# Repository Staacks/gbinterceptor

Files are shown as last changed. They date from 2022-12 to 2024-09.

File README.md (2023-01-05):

# GB Interceptor
Capture or stream Game Boy gameplay footage via USB without modifying the Game Boy.

This open source and open hardware Game Boy adapter uses an rp2040 to capture the communication on the cartridge bus. This data is fed into an emulator, rendered and then offered as a USB video class device.

Details about the concept can be found at https://there.oughta.be/a/game-boy-capture-cartridge and an overview is given in the following video:

Youtube Video: GB Interceptor: A Game Boy capture cartridge (https://youtu.be/6mOJtrFnawk)

If you have pull-requests, bug reports or want to contribute new case designs, please do not hesitate to open an issue. For generic discussions, "show and tell" and if you are looking for support for something that is not a problem in the code here, I would recommend .

<a href="https://www.buymeacoffee.com/there.oughta.be" target="_blank">Buy Me A Coffee</a>

# Warnings

Please make sure to understand what this device does and what its limitations are. Most importantly, there is a little lag which will make it unsuitable for playing on a bis screen. It might be ok for slow games, but its focus is on recording and streaming.

Also check out the compatibility tables for host software (for example OBS) and particular games. In principle this is a USB video class device and does not require drivers, but not all software supports the unsusual video format of the Interceptor. Similarly, games should usually work, but sometimes there are some details that the Interceptor does not yet support properly and some rare things that cannot work based on the principle of this device.

* [Game Boy compatibility](https://github.com/Staacks/gbinterceptor/wiki/Game-Boy-compatibility)
* [Host software compatibility](https://github.com/Staacks/gbinterceptor/wiki/Host-software-compatibility)
* [Game compatibility](https://github.com/Staacks/gbinterceptor/wiki/Game-compatibility)

# Building the Interceptor

There is an [order and build video](https://youtu.be/Lg92tVkEE98) to guide you through the build process which I highly recommend, especially if you are not used to ordering PCBs. A [written guide can be found in this repository's wiki](https://github.com/Staacks/gbinterceptor/wiki/Build-guide).

# Usage

Simply plug the Interceptor into your Game Boy and the Game into the Interceptor. Connect the Interceptor to your computer before turning on the Game Boy. It should show up as a webcam in any software that supports USB Video devices (for example OBS Studio). Note that some software is not entirely happy with the exotic format, but it should work in most cases (see [Host software compatibility](https://github.com/Staacks/gbinterceptor/wiki/Host-software-compatibility)).

Then just turn on the Game Boy and play.

Note that you do not need to open the video stream first. The only important step is that the Interceptor is powered via USB before the Game Boy is turned on.

## Buttons

The [Mode] button (next to the LEDs) allows to switch between grayscale/green colors and toggle frame blending. Each press switches colors and frame blending is toggled each time it returns to grayscale.

The [Flash] button (near the center, usually inside the case) is only used to flash a new firmware version. Simply hold it while plugging in the USB cable. The Interceptor should appear as a storage device (like a USB stick) and you can simply drag the new firmware file (a uf2 file) into it.

## LEDs

The red LED indicates that the Interceptor is powered.

The blue LED stays on as long as the Interceptor is in sync with the game. (It may shortly turn off for a fraction of a second when the Game Boy turns the display off, i.e. when loading a level.)

# Support

While I do not give any guarantees I (and probably others too) am happy to help if I have the time.

If you are having difficulties to order, build or use your Interceptor, please do not contact me directly but use [r/thereoughtabe on reddit](https://www.reddit.com/r/thereoughtabe/) as this allows others to help and the answer might help others, too.

If you found a bug and in particular if you find glitches in a game, please check the [compatibility lists](https://github.com/Staacks/gbinterceptor/wiki) in the Wiki first to see if it is a known problem and open an issue here on Github otherwise.

# Building the firmware

Most users should just install the latest release uf2 as described in the [Build guide](https://github.com/Staacks/gbinterceptor/wiki/Build-guide), but if you want to build it yourself, you will need the [Raspberry Pi Pico SDK](https://github.com/raspberrypi/pico-sdk). Don't forget to set PICO_SDK_PATH accordingly.

Make sure to check out the submodules too and specifically make sure that the [TinyUSB](https://github.com/hathach/tinyusb) submodule is at least on version 0.14.0 as the Pico SDK currently references an older version. (Also see [#3](https://github.com/Staacks/gbinterceptor/issues/3))

# License
The code is released under the GNU General Public Licence 3 and the design files (PCB layout and 3d printed case) are released under the Creative Commons licence CC-BY 4.0.

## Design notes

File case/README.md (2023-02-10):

# GB Interceptor Case

These are various resources and design files for cases for the GB Interceptor. The 3d-printed one referenced in the Youtube videos and the build guide [build guide](https://github.com/Staacks/gbinterceptor/wiki/Build-guide) can be found in the folder 3dprint. 

**You can find more options by the community by looking at the [case guides](https://github.com/Staacks/gbinterceptor/wiki#case-options) on the Wiki.**

# Important note about the break-out extension board

If you want to create a custom case using the extension board to place the cartridge slot in a more flexible manner, please take special care to correctly match the pins. For this, ignore the silklayer (printing) ob the PCB and look at the position of pin one, which is the one with the square pad (the others are circular). The printed outline on the PCB may work fine for jumper wires or special connectors, but with the normal ribbon cable connectors (known from old disk drives) the pin headers of either the extension board or the GB Interceptor need to be soldered onto the opposite side of the board in order for the pins to match. Therefore, keep track of pin one when creating your own solution.

# Folder list

Please, find details about each option in the [case guides](https://github.com/Staacks/gbinterceptor/wiki#case-options) on the Wiki.

* __3dprint__  
  The original 3d printed case as discussed in the videos.
* __3dprint-angryhelder__  
  Variant by AngryHelder (Helder Silva) of the original 3d printed case. These are step files derived from the original 3dprint case to allow for easy adaption into new case projects. It also includes a version that is easier and nicer to print but requires glueing.

# License

The design files are licensed under the Creative Commons Attribution License (CC-BY 4.0).

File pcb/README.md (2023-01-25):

# GB Interceptor PCB

These are the design files for the PCB of the GB Interceptor. See the [build guide](https://github.com/Staacks/gbinterceptor/wiki/Build-guide) for details.

# License

The design files are licensed under the Creative Commons Attribution License (CC-BY 4.0).

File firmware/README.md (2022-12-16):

# GB Interceptor Firmware

This folder contains the source code for the firmware of the GB Interceptor. It requires the Raspberry Pi Pico SDK as well as TinyUSB (which is usually a submodule of the Pico SDK repository). If you want to build the firmware yourself, remember to set `PICO_SDK_PATH` correctly.

The subfolder screens contains the info screens shown when no game is running. The `sh` script in the same folder can be used to convert new images to header files.

# License

This code is licensed under GNU General Public License v3.

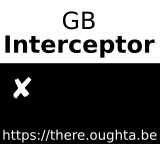
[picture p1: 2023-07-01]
firmware/screens/off.png

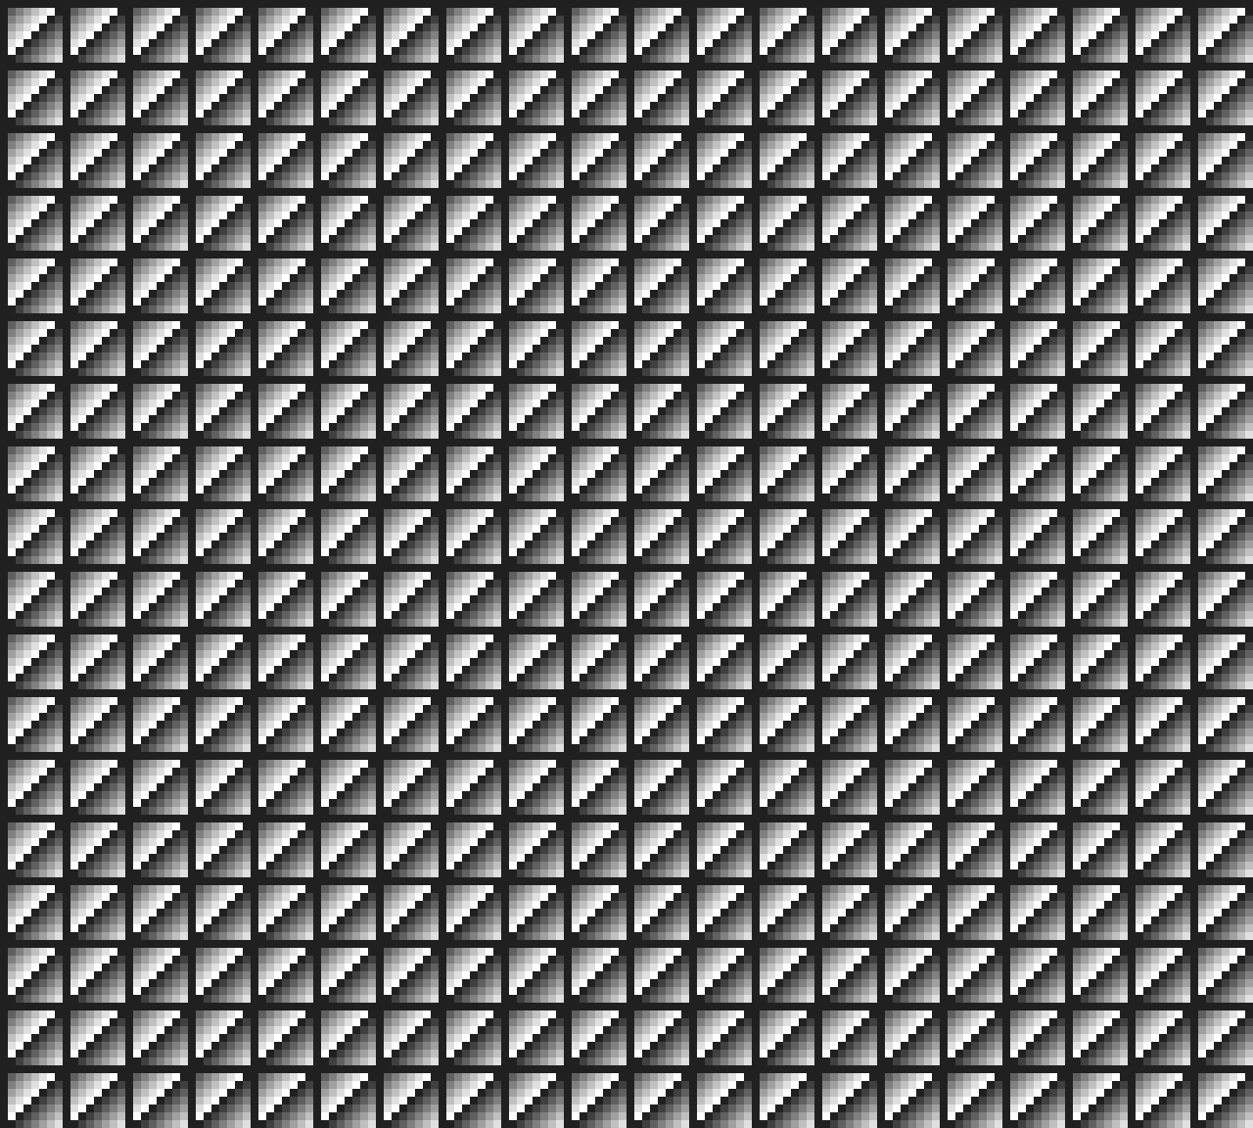
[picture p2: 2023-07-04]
firmware/jpeg/base.jpg

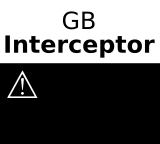
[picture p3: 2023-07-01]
firmware/screens/error.png

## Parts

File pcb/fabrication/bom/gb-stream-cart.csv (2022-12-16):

Comment | Designator | Footprint | LCSC
10u | C1,C4,C17 | Capacitor_SMD:C_0805_2012Metric | C440198
30p | C2,C3 | Capacitor_SMD:C_0402_1005Metric | C1570
100n | C5,C6,C7,C9,C11,C12,C13,C14,C15,C16,C18,C19,C20,C21,C22,C23,C24,C25 | Capacitor_SMD:C_0402_1005Metric | C1525
1u | C8,C10 | Capacitor_SMD:C_0402_1005Metric | C52923
LED BLUE | D1 | LED_SMD:LED_1206_3216Metric | C130717
LED RED | D2 | LED_SMD:LED_1206_3216Metric | C84270
USB_C_Receptacle_USB2.0 | J1 | Connector_USB:USB_C_Receptacle_HRO_TYPE-C-31-M-12 | C165948
1k | R1,R5 | Resistor_SMD:R_0402_1005Metric | C11702
5.1k | R10,R11 | Resistor_SMD:R_0402_1005Metric | C25905
27 | R3,R4 | Resistor_SMD:R_0402_1005Metric | C25100
470 | R6 | Resistor_SMD:R_0402_1005Metric | C25117
2.2k | R7,R8 | Resistor_SMD:R_0402_1005Metric | C25879
3.3k | R9 | Resistor_SMD:R_0402_1005Metric | C25890
SW_Flash | SW1 | Button_Switch_SMD:SW_Push_1P1T-SH_NO_CK_KMR2xxG | C72443
SW_Mode | SW2 | Button_Switch_SMD:SW_Push_1P1T-SH_NO_CK_KMR2xxG | C72443
NCP1117-3.3_SOT223 | U1 | Package_TO_SOT_SMD:SOT-223-3_TabPin2 | C146799
W25Q128JVS | U2 | Package_SO:SOIC-8_5.23x5.23mm_P1.27mm | C97521
RP2040 | U3 | RP2040_minimal:RP2040-QFN-56 | C2040
SN74LVC4245A | U4,U5,U6,U7 | gb-stream-cart:SN74LVC4245APWR | C7859
TAXM12M2GLFBET2T | Y1 | RP2040_minimal:Crystal_SMD_HC49-US | C111117

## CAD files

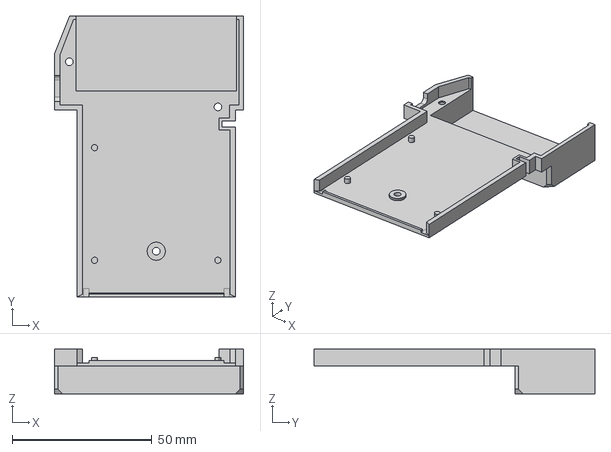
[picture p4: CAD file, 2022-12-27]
case/3dprint-angryhelder/GB Interceptor Bottom.step
67.9 x 100.7 x 16.0 mm

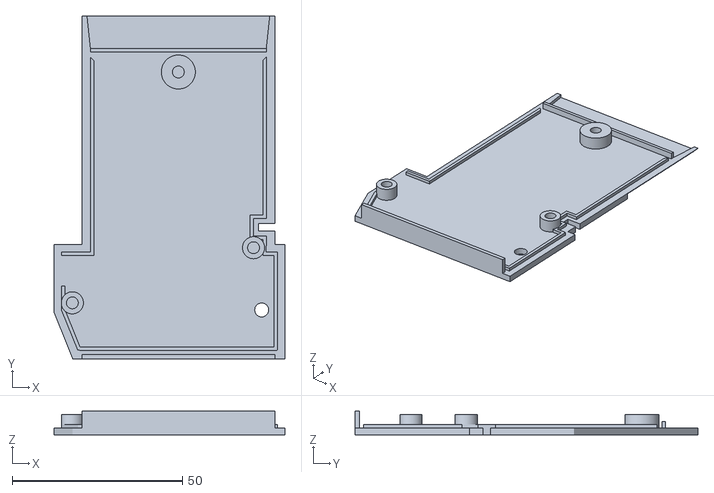
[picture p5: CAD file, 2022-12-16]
case/3dprint/case_top.stl
67.9 x 100.7 x 7.00

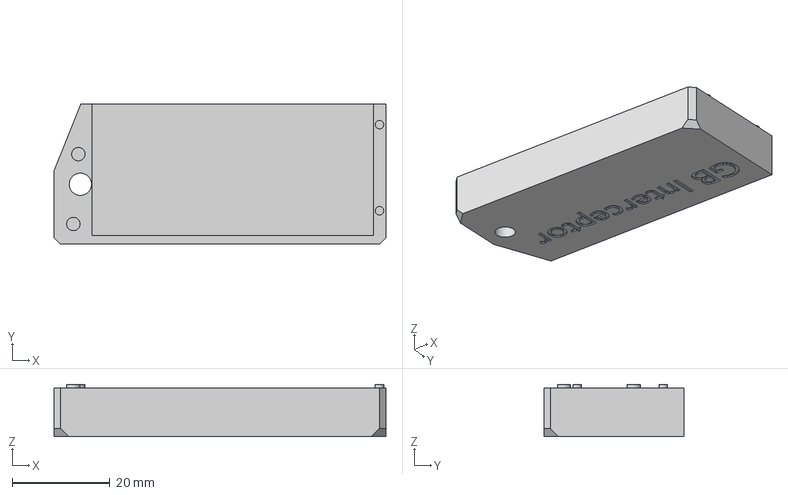
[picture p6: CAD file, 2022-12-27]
case/3dprint-angryhelder/GB Interceptor Bottom Cap.step
67.9 x 28.7 x 10.7 mm

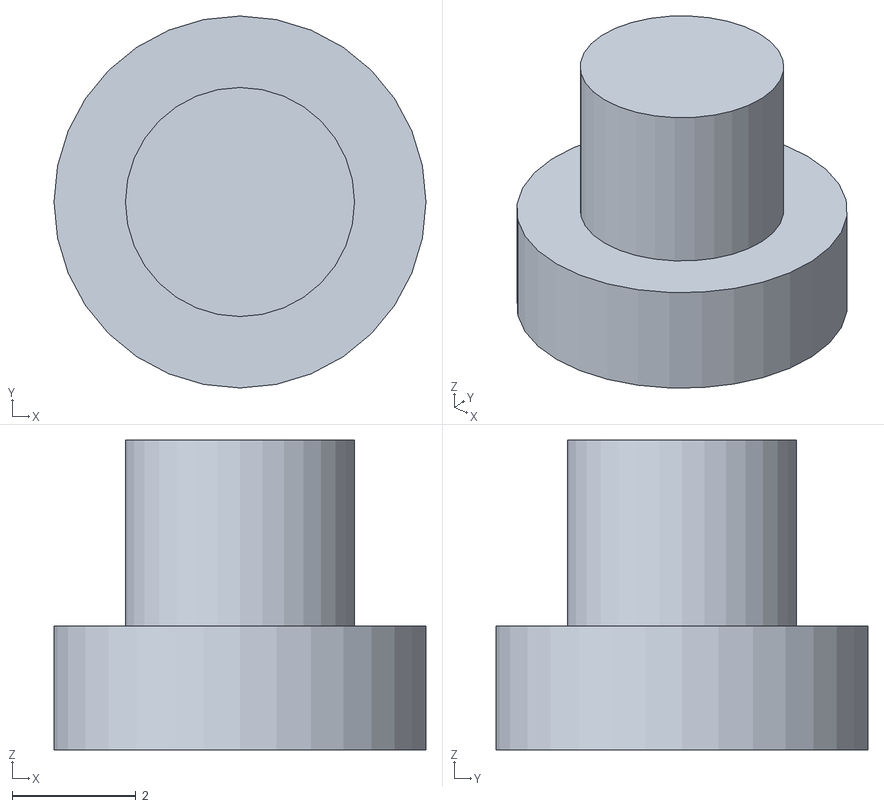
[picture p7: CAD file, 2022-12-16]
case/3dprint/case_button.stl
6.00 x 6.00 x 5.00

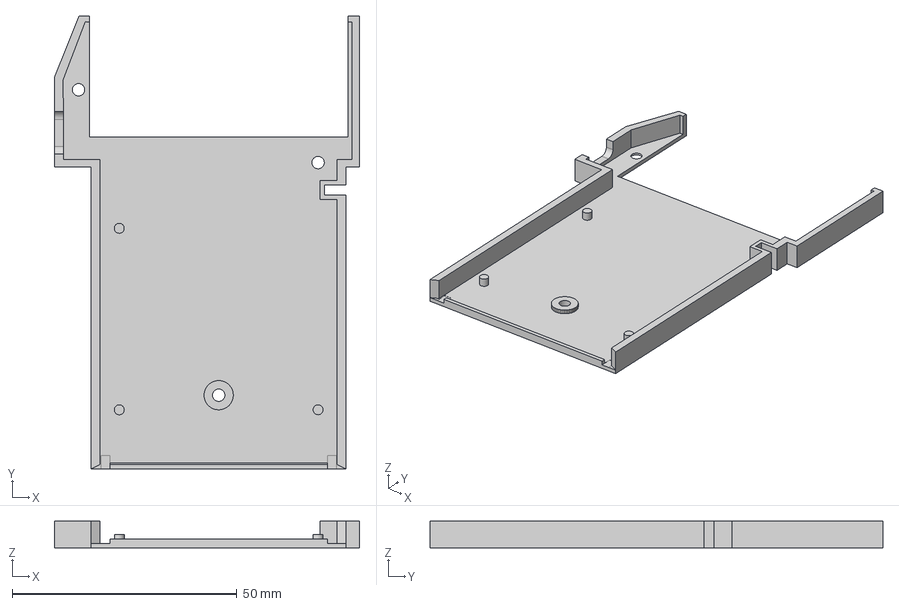
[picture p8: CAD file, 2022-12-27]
case/3dprint-angryhelder/GB Interceptor Bottom Base.step
67.9 x 100.7 x 6.00 mm

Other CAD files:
case/3dprint/case_bottom.stl
case/3dprint-angryhelder/GB Interceptor Top.step
case/3dprint-angryhelder/GB Interceptor Button.step
case/3dprint/case.blend

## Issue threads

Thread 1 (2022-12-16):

Corrupted image on MacOS on Apple CPUs

Staacks, 2022-12-16:
While the system and software recognizes the GB Interceptor, no image is received.

On first tests, the following could be found:
* Tested and not working: FaceTime, VLC, OBS, ffmpeg (on the command line)
* As not even ffmpeg and OBS get an image, I suspect that this is not an issue of the host software, but the system's USB video class driver
* The GB Interceptor does not even notice that the system requests a video stream and does not try to send a single frame.

Staacks, 2022-12-27:
**Update**:

The next release will work on MacOS to some extend. I got it to work on an Intel MacBook, but not on an M2 and I highly suspect that there is a bug in the driver for Apple silicon. The fix to at least get it to work on the Intel MacBook is in TinyUSB where I will set up a Pull Request next, so there is no commit here to reference at the moment.

Also, there is still some flickering going in case of the MacBook that works, but I have an idea what might be the cause and might be able to fix this when implementing selectable framerates...

For those Apple devices on which it will not work, we will have to wait for a fix from Apple or for a solution through a Python script without the USB video class.

Staacks, 2023-01-06:
Just some data that seems to confirm my suspicion that it is an M1/M2 thing (although a few more Intel data points would be nice)  collected from the community on Mastodon and Twitter:

Working correctly on:
MacBook Pro with **Intel** CPU that I tried
MacBook Pro (A1990) with **Intel** from #5

Green distorted image on:
MacBook Air (2022) with **M2** that I tried
MacBook Air **M1** from [@martino_](https://twitter.com/martino_/status/1610707330034987008?s=20&t=GkvNPQvVvC96-_PwVkOMTQ)
MacBook Air **M2** from [@dead_smed](https://twitter.com/dead_smed/status/1610688835981119489?s=20&t=GkvNPQvVvC96-_PwVkOMTQ)
2020 16GB **M1** Mac Mini from [@juri](https://infosec.exchange/@juri/109632195001058647)
2020 8GB **M1** MacBook Air also from [@juri](https://infosec.exchange/@juri/109632195001058647)

I am not entirely convinced that it is NV12 triggering the bug as my research at least found some reports of different NV12 devices that work on Apple silicon. But since it works on Intel-based Macs as well as Windows and Linux I still think it is either a Bug at Apple's end or at least a detail that the M1/M2 version is extremely picky about. If only I knew what triggers the issue.

LordRembo, 2023-02-01:
I tried on 2 Macbook Pro: a 2015 model and a 2017 model (first one with a touch bar).
It didn't work on Mojave (macos v10.14) -> just green image
But it started working when I upgraded the OS. I'm currently on Monterey on the oldest (v12) and Ventura on the other (v13) and the image is fine.

Staacks, 2023-02-01:
Interesting detail about Mojave. I had only tried newer versions where Intel works but M1/M2 does not. Not sure if that is related, though.

Staacks, 2023-06-17:
I just managed to get a MJPEG version of the Interceptor up and running (see #17) and it worked perfectly on an M2 MacBook Air (https://mastodon.social/@DiConX/110561770831634636).

So, I am very optimistic, that the next update will finally have full Mac compatibility.

Staacks, 2023-07-02:
Here is the first test release with MJPEG output which should fix Apple compatibility:
https://github.com/Staacks/gbinterceptor/releases/tag/v1.2.0-beta1
Please test and report back.

Staacks, 2023-08-05:
Just released version [v1.2.0](https://github.com/Staacks/gbinterceptor/releases/tag/v1.2.0) which contains the fix.

Closed 2023-08-05.

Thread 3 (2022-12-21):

Build firmware instructions

vChavezB, 2022-12-21:
**Describe the bug**
I cannot build the firmware with the latest rpi-pico sdk.

**To Reproduce**
```bash
git clone https://github.com/raspberrypi/pico-sdk --recurse-submodules
git clone https://github.com/Staacks/gbinterceptor
cd gbinterceptor/firmware
mkdir build && cd build
cmake .. -G Ninja -DPICO_SDK_PATH=../../../pico-sdk
ninja
```

**Expected behavior**

No compiler errors when building and binary output in cmake output directory.

**Error**

```bash
/gbinterceptor/firmware/main.c:265:69:` error: unknown type name 'video_probe_and_commit_control_t'
  265 | int tud_video_commit_cb(uint_fast8_t ctl_idx, uint_fast8_t stm_idx, video_probe_and_commit_control_t const *parameters) {
```

After I add this to tusb_config.h

```c
// RHPort max operational speed can defined by board.mk
// Default to Highspeed for MCU with internal HighSpeed PHY (can be port specific), otherwise FullSpeed
#ifndef BOARD_DEVICE_RHPORT_SPEED
  #if (CFG_TUSB_MCU == OPT_MCU_LPC18XX || CFG_TUSB_MCU == OPT_MCU_LPC43XX || CFG_TUSB_MCU == OPT_MCU_MIMXRT10XX || \
       CFG_TUSB_MCU == OPT_MCU_NUC505  || CFG_TUSB_MCU == OPT_MCU_CXD56 || CFG_TUSB_MCU == OPT_MCU_SAMX7X)
    #define BOARD_DEVICE_RHPORT_SPEED   OPT_MODE_HIGH_SPEED
  #else
    #define BOARD_DEVICE_RHPORT_SPEED   OPT_MODE_FULL_SPEED
  #endif
#endif

// Device mode with rhport and speed defined by board.mk
#if   BOARD_DEVICE_RHPORT_NUM == 0
  #define CFG_TUSB_RHPORT0_MODE     (OPT_MODE_DEVICE | BOARD_DEVICE_RHPORT_SPEED)
#elif BOARD_DEVICE_RHPORT_NUM == 1
  #define CFG_TUSB_RHPORT1_MODE     (OPT_MODE_DEVICE | BOARD_DEVICE_RHPORT_SPEED)
#else
  #error "Incorrect RHPort configuration"
#endif
```
It starts to compile alas I get more errors due to macros not being defined.

```bash
/gbinterceptor/firmware/usb_descriptors.h:29:86: error: 'TUD_VIDEO_DESC_CAMERA_TERM_LEN' undeclared here (not in a function); did you mean 'TUD_VIDEO_DESC_INPUT_TERM_LEN'?
```

I suspect the firmware was developed for an older version of the rpi-pico sdk, could you mention which tag or hash commit you used from the rpi-pico sdk to reproduce the build.

vChavezB, 2022-12-21:
I attempted again to build the project and now it works. Fixed by updating the tinyusb git submodule from the hash commit 4bfab30c02279a0530e1a56f4a7c539f2d35a293  to the latest release tag 0.14.0.

```
git clone https://github.com/raspberrypi/pico-sdk --recurse-submodules
cd pico-sdk/lib/tinyusb && git checkout 0.14.0 && cd ../../../
git clone https://github.com/Staacks/gbinterceptor
cd gbinterceptor/firmware
mkdir build && cd build
cmake .. -G Ninja -DPICO_SDK_PATH=../../../pico-sdk
ninja
```

Staacks, 2022-12-21:
Thanks. That should help others. I will add a note about it to the readme.

maehw, 2024-01-02:
Thanks for the additional steps. I hope it's okay when I comment on the same issue:

My build shows a warning. Can it be ignored? Or did I miss to configure something?

```
...
[76/107] Building C object CMakeFiles/gb_interceptor.dir/<some_folder>/pico-sdk/src/rp2_common/pico_stdio_usb/stdio_usb.c.obj
/<some_folder>/pico-sdk/src/rp2_common/pico_stdio_usb/stdio_usb.c:245:2: warning: #warning stdio USB was configured along with user use of TinyUSB device mode, but CDC is not enabled [-Wcpp]
  245 | #warning stdio USB was configured along with user use of TinyUSB device mode, but CDC is not enabled
      |  ^~~~~~~
[107/107] Linking CXX executable gb_interceptor.elf
```

Staacks, 2024-01-05:
Sorry, I had not noticed that warning before. It should not be a problem, though. Earlier versions of the GB Interceptor firmware had a USB serial endpoint enabled by default which I used for debugging. In recent builds I disabled it which basically means that debug message end up nowhere (but those are not triggered while the game is running anyway) unless I explicitly enable the CDC endpoint.
If the warning bothers you, you can simply set `pico_enable_stdio_usb` to `0` in https://github.com/Staacks/gbinterceptor/blob/0ad6aeca61dd41e7142bce1b27133061fd0e713e/firmware/CMakeLists.txt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
but if I am not mistaken, that should not make a difference except for the warning.

maehw, 2024-01-13:
I know this issues is closed and I wonder if I should open a new one.

The firmware builds fine. However, when I build locally, my .uf2 file does not run properly. The USB device is listed but when I open it in VLC, I don't see nothing. I've tested this on a GB Interceptor I bought online (https://chaos.social/@maehw/111744070372283492).

Overwriting my locally built one with the release version from github (https://github.com/Staacks/gbinterceptor/releases/tag/v1.2.0) makes it work again. I am quite sure this is not related to the hardware but to my local build. (I use the same git commit, i.e. 0ad6aec - the current HEAD).

Mine: filesize: 605184 bytes, md5 hash: 18781f9109015cc79da16a937391e52c
Mine (when pico_enable_stdio_usb=0): filesize: 605184 bytes, md5 hash: f76dc473397d599912e86ea8e1f09b72
Yours: 605696 bytes, md5 hash: 3207bb44884632f2e607a68629175718

How could I debug this in the best way? Binary diff the .uf2 files, the .hex files?
I use pico-sdk commit 6a7db34 (tag: 1.5.1).

Sorry if I missed something.

Staacks, 2024-01-14:
Sorry, I don't have much spare time at the moment, but hopefully I can try a build with entirely clean pulls this evening.

However, I already have a suspicion since you mentioned your pico-sdk version: They still seem to include an old commit of TinyUSB as a subrepository that did not yet include bulk transfer for UVC. I suspect that I pulled the latest commit in this subrepo without realizing that others trying to build would no know about it. So, if you pull the latest TinyUSB in the pico-sdk lib folder, does it fix the build for you?

maehw, 2024-01-14:
Thanks for having a look into this! It's very much appreciated.

I tried to pin pico-sdk to commit hash 2e6142b15b8a75c1227dd3edbe839193b2bf9041 and then pin lib/tinyusb to tag 0.14.0, i.e. commit hash 9e91b02ec7fb3502747b5c413a4824654fa7fc7e as mentioned above.

However, this throws TUD_VIDEO_DESC_* errors. This can be reproduced locally and with the [GitHub Actions CI](https://github.com/maehw/gbinterceptor/blob/2ce27167931e50e511fd63641261cbe4742cf87c/.github/workflows/main.yml))

https://github.com/maehw/gbinterceptor/actions/runs/7519981657/job/20469147860 (Build log)

Staacks, 2024-01-15:
Again sorry, did not get around to try today, so just one quick observation and hopefully testing tomorrow:
tinyusb should be at least 0.16.0, because that's when bulk transfer streaming for UVC was introduced.

maehw, 2024-01-15:
No worries, Sebastian. Thanks for your quick help - and making your baby an open source software project!

Your hints finally helped, see #26 👍

I pinned pico-sdk to 1.5.1 and tinyusb to 0.16.0 (the most recent release versions speaking of today).

As the include file ...

```
#include "bsp/board.h"
```

seems to have moved, I replaced it by

```
#include "bsp/rp2040/board.h"
#include "bsp/board_api.h"
```

which makes it build again. (Not sure if this is 100% clean, but it does the trick.)

Happy to hack on this now:

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

vChavezB, 2024-01-18:
just as a sidenote: would be nice to add a github actions to this project to reproduce the builds 👍

Staacks, 2024-01-18:
I know... @maehw has already submitted a [pull request](https://github.com/Staacks/gbinterceptor/pull/26). Since I have never used this before I want to take some time to properly look into it, but I am just pushing it up and down my todo list as I am a bit swamped at the moment.

Closed 2022-12-21.

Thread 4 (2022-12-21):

Does not recognize second boot on special cartridges with menus (i.e. Everdrive, Game Genie, etc.)

Staacks, 2022-12-21:
The Interceptor waits for a request to address 0x0100 to recognize the start of the game. When there is an error or the game halts too long, it shows an info screen, but will not again wait for 0x0100 unless the Game Boy is turned off and on again. While this makes sense for regular games, it interferes with some special cartridges, that show a menu before loading a game and reset without turning off.

To fix this, the Interceptor simply needs to allow for a second boot within a short time frame.

**Workaround until this is fixed:**
Plug in the USB cable for the Interceptor when the special cartridge is already showing its menu.
(This way it misses the first 0x0100 and starts with the 0x0100 from the actual game. You won't see the menu on the Interceptor, though.)

Staacks, 2022-12-29:
Uhm... github was a bit fast here. I leave it open until someone with an Everdrive reports back.

Staacks, 2022-12-30:
Confirmed to fix the problem for the Everdrive.

domis4, 2023-04-03:
have this issue with the EZ Flash JR. (besides the already known graphical issues)

can i support or help here?

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

Staacks, 2023-04-03:
Wait, this only happens when the EZ Flash reboots? This looks exactly like the MacOS problem on M1 and M2 macs and the original EZ Flash problem was already resolved a while ago and was simply the problem that the Interceptor did not recognize that the Game Boy restarted and was stuck on the error screen. This is a USB Video problem and I am scratching my head how it would be related to a reboot of the EZ flash. Also, I am using an EZ Flash Jr. all the time to test game-specific problems...

So, let's start collecting a few details:
- Which firmware are you using (and if not the latest, please try the latest one).
- Can you tell me step by step what you do and what the Interceptor shows? Especially, what part looks correct, which status/error screens are shown (even for a fraction of a second) and what the blue LED on the back does.
- Can you also show a Windows screenshot? I am wondering if it is the MacOS issue on Windows, too, or if we are looking at two problems at the same time.
-

domis4, 2023-04-03:
My steps where the following and reproduceable:

Windows 11:
1. Plug in Everything (GB Interceptor into GBC, Cardridge into GB Interceptor, USB C into Windows 11 PC)
(no LED)
2. Launch OBS and select a new Scene with the GB Interceptor
(no LED)
3. Power on the Gameboy, wait until the screen is visible in OBS
(red LED, until OBS picked a signal, then both LED)
4. Launch a Game
(red LED only)

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

Staacks, 2023-04-03:
Thank you for your e-mail. I will be out of office until 11th April and my response may take longer than usual.

Best regards,
Sebastian Staacks

Staacks, 2023-04-03:
Thanks, so the green video problem is the known MacOS issue. (Or is the EZ Flash menu normal on the Mac?)

But I am afraid that Pokemon Crystal is not a good example, because that is a Game Boy Color game which is not supported by the Interceptor. I would guess that the error is not from the second boot but from the GBC game entering double speed mode. Do you have the problem with classic games, too?

domis4, 2023-04-05:
well, thats embarrsing. It works perfectly on .gbc games 🤦‍♀️ how could i forget that crystal is a gbc only game. Thanks for your fast replies!

Closed 2022-12-30.

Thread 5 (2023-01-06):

GB Interceptor displaying mirrored video on GameBoy Pocket

tylerbartlett, 2023-01-06:
GB Interceptor displaying mirrored video on GameBoy Pocket (Model: MGB-001)

I have experienced the same mirroring on Windows 10 desktop and Mac laptop. I did use Discord to test on both OSs. Using firmware v1.0.1. I dont have another gameboy to test with to see if its a pocket specific issue, but will try to scrounge one up.

Staacks, 2023-01-06:
Are you sure that the image actually comes mirrored from the Interceptor? I just checked and Discord's is showing a mirrored preview. Most video chat software does this, so you see yourself like in an actual mirror, which is more comfortable to most people, but the image seen by others should not be mirrored. (Often video chat software also has a button to change this behavior but I could not find one on the Discord webinterface.)

Could you please confirm if the image is also mirrored to others who see your image on Discord or if it is flipped in other software, too (for example in OBS Studio or VLC (on the Mac, the Win version is still causing trouble)).

BTW: Since you mention a MacBook: If it is working there, could you please tell me the model (especially whether it is one with an Intel CPU or a M1/M2). I am still trying to figure out #1 and need some info about those Macs on which it works. And yes, FaceTime and PhotoBooth mirror the image, too.

tylerbartlett, 2023-01-06:
Hi Sebastion, I checked on the preview situation and everything you said is right. With a second computer I joined discord and the output is not mirrored there.

As far as the Mac its an Intel CPU, but I'll post over in that issue with more info.

I consider this issue to be closed with resolution. Thank you!

Staacks, 2023-01-06:
Perfect, thanks. I will add a note on this to the trouble shooting section and the Game Boy Pocket to the list of working devices

Closed 2023-01-06.

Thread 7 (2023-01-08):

Fortified Zone

Megabusterretro, 2023-01-08:
**Type of issue**
Interceptor reports error / Game looks different from Game Boy screen / other
**Black Screen when starting main gameplay**
**Describe the bug**
A clear and concise description of what the bug is.
**Game starts without issue, able to start the game but once the first gameplay screen appears the Interceptor screen goes black.**
**To Reproduce**
Steps to reproduce the behavior:
**1. Start Game**
2. Click on '....'
3. Scroll down to '....'
4. See error

**Screenshots**
If applicable, add screenshots to help explain your problem.

**Host software (please complete the following information):**
 - OS: [e.g. Windows, MacOS, Linux, ...]  **Windows**
 - Software: [e.g. OBS, VLC, ffmpeg, Zoom, ...]  **OBS**

**Game Boy:**
- Model: [e.g. Game Boy Advance AGB-001] **Funnyplaying IPS modded DMG and IPS Modded GBC**

**Game:**
- Title: [e.g. Tetris] **Fortified Zone**
- Version: [Usually printed on the cartridge, e.g. DMG-ZL-NOE]  **DMG-IY-USA**

**Additional context**

Add any other context about the problem here.
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

Staacks, 2023-01-08:
Jepp, I can reproduce both problems: The glitch during the title screen effect does not surprise me much. The PPU emulation timing can certainly use some improvement and this looks like a good candidate to work on a few details.

In terms of the black screen I have no idea right now what is happening. I did not expect this and the fact that it remains black even if you restart the game seems like it is not just an emulation problem, but a more basic bug of the Interceptor.

Will hopefully find some time to look into it in a few days.

Megabusterretro, 2023-01-08:
Sounds good!  I have probably ~200 game boy games that I can test for functionality if you would like.  Would this be the best method of submitting a list of verified working titles?  Just submit a Game Bug issue and just state the list of titles working and a screenshot?

Staacks, 2023-01-09:
Woah, that would be amazing. Any form you can send me the list works for me.

Staacks, 2023-01-09:
Found the main issue of the black screen: I had the emulated div register linked to my internal clock counter, which stupidly meant that the clock counter jumps when a game resets the div register. This should be a problem for some other games too, so I directly turned it into a new release.

I don't think that I will look into the glitch of the title animation anytime soon, though. Most mid-frame effects work fine, but in this case I think it is not an issue of the inter-line timing, but the intra-line timing (if these terms are a thing). It looks to me as if the problem is that the scroll register is updated while the Interceptor is not yet finished with each line. Unfortunately, the intra-line timing is very tricky on the Interceptor because a) there are some situations in which it just cannot render fast enough and lags slightly behind (making up for it during hsync) and b) the USB communication on the same core can slightly delay the rendering of a line. So, this is a bigger thing to tackle at some point with a few creative ideas...

Closed 2023-01-09.

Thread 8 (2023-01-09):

Firmware 1.0.1 and 1.0.2 cause connecting video feed to crash - across MacOS, Windows and Android.

remy, 2023-01-09:
**Describe the bug**

Firmware 1.0.1 and 1.0.2 cause connecting software to crash - across MacOS, Windows and Android.

It looks like it's only when the video feed is probed / previewed that my software then goes into a crash.

Does not happen with 1.0.0 firmware though. I'd normally expect this is unique to my computer, but this happens across totally different devices.

I've also been able to replicate between multiple GB Interceptors with the same effect. The PCB print is from version 1.0.0 too.

**To Reproduce**
Steps to reproduce the behavior:

1. Install either 1.0.1 or 1.0.2 firmware on GB Interceptor
2. Try to view video stream using methods described in wiki

**Expected behavior**

Video stream is found and doesn't crash software.

**Host software (please complete the following information):**
 - OS: MacOS 11.7, Android (latest Google OS with Pixel 6a Plus), Windows Surface with Windows 11
 - Software:
	 - On Mac: VLC and Quick Camera - using VLC and selecting Open Capture Device, VLC then hangs until it crashes
	 - On Windows: OBS but also "Manage Camera" (note that on Windows I can see the device correct detected and listed in the device manager, but once I got to Manage Camera and select GB Interceptor, it tries to get a preview and crashes the settings panel)
	 - On Android: USB Camera (com.shenyaocn.android.usbcamera) - app will crash and immediately reopen (in the background) finding the USB connection again, but bringing the app to focus then causes it to completely crash out

**Additional context**

Am testing **without** gameboy or game attached.

I appreciate there's not a load of detail here, and I suspect this isn't happening for many/if _any_ people, so happy to add more detail where you think it would be useful.

Staacks, 2023-01-10:
ok, that is a weird one indeed, because I just tried on Windows and Mac without problems, but I can reproduce the problem on Android. And I can confirm that it is no problem with 1.0.0.
Not sure why it happens on some devices and not others, but at least I can reproduce it and have a very good starting point to narrow it down.

The strange thing is that the Apple fix in 1.0.1 of course sounds like a good candidate that influences USB behavior, but it basically only accepts a somewhat incorrect request that otherwise would have been rejected. I just hope it is one of my few changes and not something in TinyUSB which I updated for this release - then I would have to do quite a bit of diggin.

I hope I can try a few things this evening. (day job first)

remy, 2023-01-10:
I have another Windows and another Mac I can test on too - I don't particularly expect different results, but it might be worth checking on my side too.

If there's anything I can help debug or look at I'd be happy to do what I can.

remy, 2023-01-10:
Just writing to confirm - testing on the second Mac (different model and older MacOS) and the same thing happened. I tried it with VLC and when I opened "Open Capture Device", VLC crashed out.

Staacks, 2023-01-10:
Ha! First change from 1.0.0 to 1.0.1 I checked resolved the issue for the Android app: With 1.0.1 I set the allowed fine control of frame rates to 100ns intervals - effectively allowing any framerate below 29fps. If I only allow larger intervals the app works fine. These fine intervals should only offer more options to the app, but I assume that this particular app tries to enumerate all possible options and that allowing anything leads to too more options than it can handle. Anyhow, here is a test build with the fix:

[gb_interceptor_1.0.3-alpha1.uf2](https://cloud.tankwar.de/index.php/s/qJryDySDeTpiD8o)

Please check if it solves the issue on Android for you, too.

Unfortunately, I am a bit skeptical that this also resolves the other issues, because if the other apps were susceptible to this problem, I should be able to reproduce it here, too.

If it does not resolve the issue for the other apps:
- Did you try 1.0.0 on those apps, too? So, can I still assume that it is a change to 1.0.1 that broke the other apps for you?
- Could you try a different cable? I know that this sounds like one of those out-of-ideas suggestions (especially when we are only running a 1MB/s stream over a USB-C cable), but I once had a similarly weird issue that was fixed by a different cable. (Would not explain why 1.0.0 worked, though)
- Do you have a Raspberry Pi Pico? If so, you can simply upload the uf2 file to that one, too, and should be able to see the standby screen using the Pico. Again, this would not fit that 1.0.0 works, but it would be a way to rule out hardware issues with your particular Interceptor.

remy, 2023-01-10:
So, 1.0.3-alpha1 worked on Android.

Then I went back to 1.0.2 and thought about the cable. I had originally tried two different cables, but both were USBC to  USBA with an adapter back to C.

I tried a USBC to USBC cable, and that was it - it started working on the Mac. I'd be willing to be it'll work on the Windows machine too (I don't have it at hand, but I will do later on).

I can't quite think why it would make a difference, the 160x144 video stream surely can't require whatever the USBC 'many-pins' offers, but apparently it does make a difference.

I can still try directly loading to a Pico if that's useful (to you for testing), but I hadn't tried it yet.

Staacks, 2023-01-10:
No, thanks, I think the Pico test is not necessary then. I think I have to do some reading on USB at that point to understand this. I know that even though it is only 160x144, the Interceptor can still be a problem because if I understand correctly USB 3 is treated separately and the bandwidth for the slower standards is still limited, especially with isochronous transfer. But I have no clue how the cable plays into that and indeed why a cable that happily handles USB 3 could be a problem here. Maybe my design of the USB line is not ideal.

I will close this issue for now and add a note on this to the trouble shooting guide.

Staacks, 2023-01-12:
Just a quick question as I am still working on the Apple issue: Is it working on both Macs and can you tell me the models? (in particular if they are Intel-based or M1/M2 models)

remy, 2023-01-12:
I'll check the other Mac in the morning (it's my wife's which she uses for
work), but neither are M1/2 Mac's - they're the intel flavour.

On Thu, 12 Jan 2023, 20:32 Sebastian Staacks, ***@***.***>
wrote:

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

Staacks, 2023-01-13:
Thanks, I just filed a bug report with Apple yesterday, referenced #1 and hope that a few more samples of working Intels vs. not working M1/M2 makes it clearer that even if there is a bug in the Interceptor there at least is an inconsistency at their and on how their devices handle it.

remy, 2023-01-13:
Completely unrelated, but I didn't want to open an issue just for this question: what does the mode button do on the PCB?

Staacks, 2023-01-13:
It toggles between gray and green colors as well as frame blending on/off. (While the game is running, firmware version 1.0.3 also shows the state of the frame blending on the screen when it changes)

LordRembo, 2023-02-01:
I've been testing firmware 1.04, with a Game Boy Camera as a webcam.
Using it with Google Meet, on an Intel MacBook Pro from 2015, with Monterey on it (macos v 12.6).
The feed as-is works flawlessly. It's just when running it through OBS and using it as a Virtual Camera that the feed starts breaking down.
In my case: previewing in OBS is fine, but running the Virtual Camera through Google Meet causes lagging (constant flashes of green screen between frames) and every now and then the camera just turns of completely.

I don't think it's a problem, and certainly not something the firmware should solve. Nobody is going to use this setup for real and I don't know how it holds up with another service. Just thought I'd mention this here for posterity and I'm curious how other people's experiences are with it as a webcam.

Staacks, 2023-02-01:
First of all, thanks for another working data point on an Intel Mac :) If only Apple would even look at the bug report I sent them...

There are two details that might help me understand the issue:
- Are the issues only visible in Google Meet while the preview in OBS remains stable or is the breakdown also visible in the OBS preview while Google Meet is running?
- Does it help if you explicitly set the framerate in the source settings for the Interceptor in OBS to a lower value, like 25 fps?

LordRembo, 2023-02-01:
No problem! Would be nice if Apple got their act together, but alas.
- The OBS preview itself is stable, no issue there.
- The lowest frame rate I could choose in OBS was 10fps and the results are always the same. I also tried various video qualities from 1920x1080 all the way down to 1024x576 (my screen ratio is 16:9)

In Google Meet itself, I set the quality at the lowest (for the video's I'm seeing as well as what I'm streaming).
It's unfortunate Google Meet doesn't have much in the way of settings so I couldn't try more than that.

Staacks, 2023-02-01:
No, wait, now that I read it again, it is going through OBS after all...?
In that case: What happens if you use a different source in OBS. Or maybe even more interesting: Running the Interceptor in the same frame as some other source, side-by-side. I am wondering if it really is an Interceptor issue if it reaches OBS without flickering and problems only occur after the composited image is pushed through OBS's virtual webcam.

LordRembo, 2023-02-01:
Good catch, can't believe I didn't think of that. I did some more testing by 1) routing the built-in camera of the MacBook into OBS as source for the virtual webcam and 2) combining the built-in cam as well as the Interceptor. Used with Google Meet as well as an alternative conferencing service for comparison (Jitsi).
In all combinations, both conferencing services give green screens with some flashes of images/blackness when using the OBS virtual cam. So seems it has nothing to do with the GB Interceptor, it's just the online services (on Mac at least) that are terrible :D
Thanks for taking a look along!

Staacks, 2023-02-01:
Good to know. Unfortunately, the Virtual Cam does not have many settings to play with, but since OBS has more users than the Interceptor that should be something that might have been observed and maybe solved by other users...

Closed 2023-01-10.

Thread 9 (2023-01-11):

Tested Games

Megabusterretro, 2023-01-11:
Here is a list of the games I have currently tested and what games I tested it on.  Let me know if there is a better way for me to share this spreadsheet.  I will also upload video of each of the games with issues tomorrow and then post a link to my private youtube channel for you to view.

<html>
<body>
<!--StartFragment--><google-sheets-html-origin><style type="text/css"><!--td {border: 1px solid #cccccc;}br {mso-data-placement:same-cell;}--></style>

Title | Model | Working? | CONSOLE TESTED | Notes
-- | -- | -- | -- | --
Bart Simpson Escape from Camp Deadly | DMG-TS-USA | YES | DMG SP | Works on SP not on DMG (Have VIdeo) SCREEN FREEZES AT TITLE SCREEN
Baseball | DMG-BS-USA | YES | DMG SP |  
BATMAN RETRUN OF THE JOKER | DMG-B5-USA | YES | DMG |  
BATTLEBULL | DMG-BR-USA | YES | DMG |  
BATTLETOADS AND DOUBLE DRAGON | DMG-VN-USA | NO | DMG | TITLE SCREEN WORKS, ONCE IN GAME SCREEN IS VERY DISTORTED
BUBBLE BOBBLE | DMG-B20USA | YES | DMG |  
BUGS BUNNY CRAZY CASTLE | DMG-BB-USA | YES | DMG |  
Darkwing Duck | DMG-DC-USA | YES | DMG |  
Defender/Joust (Arcade Classic) | DMG-ADJE-USA | NO | DMG SP | Image Ghosting on SP, DMG Unplayable
F1-RACE | DMG-F1-USA | YES | DMG |  
FIGHTING SIMULATOR | DMG-HR-USA | SORTA | DMG | SPRITE DEFORMED ON FIRST LEVEL, FIXES ITSELF AT BOSS LEVEL
FORTIFIED ZONE | DMG-IY-USA | YES | DMG | NEEDS FW 1.02
GARGOYLES QUEST | DMG-RA-USA | YES | DMG |  
HOME ALONE 2 | DMG-AH-USA | YES | DMG |  
JAMES BOND 007 | DMG-AWTE-USA | YES | DMG |  
KEN GRIFFY BASEBALL | DMG-AKGE-USA | YES | DMG |  
MARIO LAND 2 | DMG-MQ-USA | YES | DMG |  
Megaman III | DMG-W3-USA | YES | DMG |  
NBA ALL-STAR CHALLENGE | DMG-AC-USA | YES | DMG |  
NHL 95 | DMG-ANHE-USA | YES | DMG |  
OPERATION C | DMG-CN-USA | YES | DMG |  
POPEYE 2 | DMG-PG-USA | YES | DMG |  
PRIMAL RAGE | DMG-AR9E-USA | YES | DMG |  
Q-Billion | DMG-QB-USA-1 | UES | DMG SP |  
RAMPAGE (BLACK GBC CART) | DMG-ARPE-USA | YES | DMG | ONLY TESTED ON DMG GAMEBOY
REN AND STIMPY VEEDIOTS | DMG-VD-USA | YES | DMG |  
RESCUE OF PRINCESS BLOBETTE | DMG-RP-USA | NO | DMG |  
REVENGE OF GATOR | DMG-PB-USA | YES | DMG |  
ROCKMAN WORLD 4 | DMG-R4J | YES | DMG | JAPANESE VERSION
ROCKMAN WORLD 5 | DMG-WMJ | YES | DMG | JAPANESE VERSION
SAMURAI SHOWDOWN | DMG-X4-USA | SORTA | DMG | GAME IS PLAYABLE BUT HEALTH BARS ON TOP ARE CUT OFF
SHANGHAI | DMG-SH-USA | YES | DMG |  
Snow Brothers | DMG-SJ-USA | YES | DMG |  
STAR WARS (CAPCOM) | DMG-WS-USA | YES | DMG |  
TECMO BOWL | DMG-TL-USA-1 | YES | DMG |  
The Cool Spot Adventure | DMG-CU-U SA | SORTA | DMG SP | Ghosting while moving
TINY TOON ADV MONTANA'S MOVIE MADNESS | DMG-T8-USA | YES | DMG |  
WWF SUPERSTARS | DMG-WX-USA | YES | DMG |  
ZOOP | DMG-AZPE-USA | NO | DMG SP | GB-I CRASHES IMMEDATELY AFTER NINTENO LOGO WORKS ON SP

<!--EndFragment-->
</body>
</html>

Staacks, 2023-01-11:
Wow, thanks a lot. Hopefully some of the crashes will be resolved with the fixes that I already created for the upcoming 1.0.3. I will go through these before release and then add them to the compatibility list.

About the ghosting: Is this the frame blending feature? If you press the mode button (next to the LEDs) twice (switches to green and back) it should be gone.
(I will add an on-screen display to make this button clearer and I will probably default to "off" as it seems to confuse more often than it helps, but it improves games that have fast flicker effects which do not translate well to the lower frame rate of the Interceptor video.)

Staacks, 2023-01-11:
No, if it is clear what happens I should be able to reproduce it with a flash cart. Also, I will probably get 1.0.3 ready this evening or tomorrow, which has a few fixes that hopefully also fix some of the problems you have found so far.

Staacks, 2023-01-11:
I just tried if some of the problems have been fixed with v1.0.3 and it seems like "Bart Simpson Escape from Camp Deadly" and "The Rescue of Princess Blobette" are fine now. Not sure about the latter, though. Can you confirm, because maybe I did not play far enough.

I still think that the two ghosting entries are the frame blending feature. The new version starts with it disabled and gives feedback on screen if you toggle it with the mode button.

About Zoop: Is GB-I the Game Boy Player? Does the problem only occur there?

Megabusterretro, 2023-01-12:
The GB-I is the GB Interceptor, sorry for the confusion!

The OSD is great!  You are right, I was tweaking with the button on the back break up some of the filament because it was snug so I must have accidentally turned blending on.  Spot worked a lot better!

Updated the firmware, and Blobette is working.  Still having issues with Camp Deadly right at the beginning.  It seems a frame updates only when something makes the screen pause.  Here is the video link:

https://youtu.be/BTohWmj9F2M (apologies for the low volume).

Staacks, 2023-01-12:
> The GB-I is the GB Interceptor, sorry for the confusion!
Ah, lol, why didn't I figure it out myself...

> The OSD is great! You are right, I was tweaking with the button on the back break up some of the filament because it was snug so I must have accidentally turned blending on. Spot worked a lot better!
No, it was on by default, but you were not the only one who disliked it in some games, so I changed it to off by default in v1.0.3. Unfortunately, it is necessary in some games. If you look at this short recording of Zelda (https://twitter.com/diconx/status/1613308004136263681), have a close look at the dog chain. On the device it looks semi-transparent because each link of the chain is only drawn on every second frame. Without frame blending you only see every second link (they seem to alternate) because the 29fps of the Interceptor only show every other frame of the (almost) 60fps Game Boy. With frame blending it still is not perfect, but all links are visible at the same time.

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

ok, I have to check both again. I am very sure that I did not see this issue, but I am not sure anymore if I tried it on the DMG or a GBC.

...and of course I have to check all the others, too. This issue will be open for a while :)

Megabusterretro, 2023-01-13:
For now, all my testing will be on my DMG so there is no confusion.  If you need me to test some specific games on other handhelds I will gladly do it.  I currently have a DMG, SP, and GBC.

Here is a few games I was able to test today.  I was on a PC without OBS so I decided to test the Win 10 Camera app..it worked like a champ to do some testing!  That is why you see another column annotating what application I tested with.

<html>
<body>
<!--StartFragment--><google-sheets-html-origin><style type="text/css"><!--td {border: 1px solid #cccccc;}br {mso-data-placement:same-cell;}--></style>
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
Staacks, 2023-01-18:
Hm... Not sure what to make of this. I expected that ground plays a role here. Anyhow, at least it seems to be narrowed down enough to not be a major problem. I will add it to the trouble shooting guide.

JJ-TerhoA, 2023-01-22:
Title || Model || Working? || Console tested || Notes || Application tested

Dr. Mario || DMG-VU-ESP || Almost working || DMG || Objects on playfield at the start of game not showing correctly. Majority of objects appear after first 4-line cleared, but not necessarily all || OBS and Kamera

SolarStriker || DMG-SS-SCN || Yes || DMG || - || Kamera

Chase H.Q || DMG-HQ-SCN || Sort of || DMG || Road and grass not uniform as should be, but otherwise game is playable || Kamera

Tom & Jerry, Frantic Antics! || DMG-J8-USA || Yes || DMG || - || Kamera

Staacks, 2023-01-26:
Damn, fixing the remaining games get's more and more tedious.

The bad news: I spend several evenings thinking about the Dr. Mario problem and I think it is the first game I give up on - at least for now. Unless I figure out an exact emulation for the div register, it seems to be unsolvable with the available resources. The problem is that it generates the level and writes plenty of random (= div register) data directly to VRAM and RAM without conditional branching.

The good news: I fixed Bonk's Adventure (see https://mastodon.social/@DiConX/109757439865554681 and https://mastodon.social/@DiConX/109757442170688549). This one creatively rearranges the bits of the gamepad input to set the mirror flag of the player tiles. So, I implemented an option to set an address specific to a game that the Interceptor tries to reconstruct by observing conditional jumps that are based on this address.

Staacks, 2023-01-28:
A few more fixes will be in 1.1.0:
- Defender (Arcade Classics 4)
- Chase H.Q.
- Battletoads (all three of them)
- Kirby's Dream Land 2
- Teenage Mutant Ninja Turtles

I think I will soon be through with the games posted here and then move on to the Google Docs list. (Well, soon depends on the games. Battletoads cost me an entire evening digging through the game to eventually find a bug in my implementation that is fixed by replacing a single character in the code...)

Megabusterretro, 2023-01-29:
That's great news!  I have been building my own list of games I've tested and will add to the sheet soon. I am also getting some Japanese games in next week I look forward to testing!

Megabusterretro, 2023-02-01:
Updated the spreadsheet with my game collection (Minus the ones listed in this thread).  Is there a Discord server to collaborate on or is Github the main source?

Staacks, 2023-02-03:
Not sure how you testers want to work. I eventually place everything in the Wiki here, because that's where others will look for information, but my list is a bit simpler and does not track testing progress across different systems.

I have now merged everything from Google Docs to this list and am working on the remaining issues. Some games have been fixed with other fixes and I aim to fix all known issues except for really difficult ones (Dr. Mario) for the release of version 1.1.0.

I had difficulties to reproduces two problems, though:
Balloon Kid: Player sprites look fine on GBC. Does this occur in a specific situation or part of the level?
Bust-A-Move 2: The bonus scores looked fine to me. I think I have seen five of them. Is it particularly rare?

Scrapz, 2023-03-09:
I figured I'll add my issue here as it seems relevant? Feel free to tell me otherwise.

I'm unable to get "Yoshi" working properly, in particular the PAL version which is called "Mario & Yoshi". Basically the same thing, except the model is "DMG-YO-AUS" as opposed to "DMG-YO-USA".

It works normally in the Gameboy, but when going through the inteceptor I get a slightly garbled Nintendo logo on boot, and the game doesn't load, and it only does it to this one game. I can play Tetris no problem, I can play Donkey Kong Land no problem. Just for some reason it corrupts Mario & Yoshi. My other games are also PAL (ie; DMG-YT-AUS) so I don't think it's a PAL compatability thing.

Is there anyone else out there with the PAL version of Yoshi that can confirm?

Staacks, 2023-03-09:
If the Nintendo logo is scrambled it's not a software issue of the Interceptor - the Interceptor does not do anything at this point and the pins of the cartridge are supposed to be directly wired to the Game Boy anyways. If the logo is scrambled the Game Boy is not able to properly read the cartridge.

If it only
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

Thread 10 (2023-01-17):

Shell for 1.6mm PCB (not a bug report)

remy, 2023-01-17:
After going backwards and forwards through JLCPCB I managed to accidentally order 1.6mm thick PCB - which obviously doesn't fit anything properly 🤦 - but I ended up creating a new shell to compensate for my mess up. I wasn't sure if you wanted to include it in the wiki (or whether you'd be happy for me to do a PR on the wiki…not sure how, but I'll learn).

URL is here: https://www.printables.com/model/371833-gb-interceptor-shell-for-16mm-pcb

Obviously ideally people get the right thickness though! 😄

Staacks, 2023-01-18:
Sure, that might help others in the same situation. I have added it to the Wiki.

Closed 2023-01-18.

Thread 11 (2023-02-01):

Feedback on PCB design

remy, 2023-02-01:
**Describe the bug**

Not a bug, more of an "in the field" use report.

One of the boards I had made I sent to a youtuber (RetroBreak) just as a thing to show off, but the first one didn't work. Couldn't work out why, but when he returned it (I sent him a new one) it turned out the pads had ripped up on the connector.

It's carnage!

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

On inspection I can see how it happened. The cart port was not 100% flat - I think there's about 0.2mm tilt. I'm not sure if that was from cart insertion or from not being entirely flat when the port was soldered down (I suspect the later).

I wondered if vias under the cart port pins would be more secure (under the actual cart port rather than below to reduce stress if it's bent) - at the same time just "be more careful" is a simpler/cheaper approach.

Obviously feel free to close this right away, just reporting it for you.

Staacks, 2023-02-01:
Well, it sounds like something I should warn about in the build guide, but I am not entirely sure yet if I understand correctly how that happened.

I assume that you have soldered the two large pads on the other side and that it is one of the cartridge slots with the two pins that fit into the holes in the PCB? I mean, I currently spent most of my evenings pulling out and re-inserting my flash cartridge to test and fix various games and my version still seems perfectly robust. Not to speak about the absurd contraption of testing a Game Genie with the Interceptor.

Was this in a 3d printed case, so that stress might be added from an edge of case pressing on the cartridge?

remy, 2023-02-01:
You know what, I now think it actually got crushed during transit when I posted the cart to the guy.

I was sure it was working before I sent it, and now looking at the cart slot side by side with another (working) Interceptor, I can see it's actually bent a little:

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

Hmm. Random bad luck on my part.

So completely ignore me - the fact that you're inadvertently stress testing (to me) definitely means there's no design flaw.

I guess the warning now is: _do not sit on GB Interceptor - does not work as a chair_!

Staacks, 2023-02-01:
:laughing:

Closed 2023-02-01.

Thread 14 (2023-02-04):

Extend length of cart connector pin pads

cristofercruz, 2023-02-04:
While soldering the cart connector to the interceptor PCB I noticed the pads only extend as far as the pins which makes it a bit harder than necessary to heat the copper pad. You might consider extending the length of those pads slightly so there is a bit of copper pad exposed at the edge where the soldering iron tip can make contact.

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

Staacks, 2023-02-10:
Good point. I don't dare updating the PCB without testing it myself and I don't want to order a batch just for this, but I will keep it open to include when enough details have accumulated for a new PCB revision.

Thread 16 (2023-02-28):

New PCB Assembly, DMG Is in a Boot Loop

Megabusterretro, 2023-02-28:
**Describe the bug**
I just purchased another batch of Interceptors.  The first two I assembled are caught in a reboot loop when I try to use them.  I have tried 3 different DMG Consoles, however, it works with an SP and several Game Boy colors.

I am including pictures of the board.
**To Reproduce**
Steps to reproduce the behavior:
1.Insert Interceptor and Game Cart to DMG Game Boy and power on

**Expected behavior**
Expectation is for the DMG to Boot

**Screenshots**
If applicable, add screenshots to help explain your problem.

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

Megabusterretro, 2023-02-28:
Just an update.  I did a third one with the same results.  DMG is in a constant reboot loop.  Here is a better view of the board as well.
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

Megabusterretro, 2023-02-28:
https://user-images.githubusercontent.com/122132860/221760840-fdb2e3f1-45ad-4eb3-8b4a-fc688e21fc28.MOV

Staacks, 2023-02-28:
ok, that's odd, especially if it is working in a GBC and SP. No idea right now, but let's clarify a few details so I am thinking in the right direction:
- Working on GBC and SP means that the "intercepted" game also shows up correctly on a PC?
- Does it also loop when no game is inserted?

Megabusterretro, 2023-02-28:
- It is showing up correctly on the PC when booting with a GBC
- No loop when there is not a game inserted.

Staacks, 2023-02-28:
Yeah, I am looking for a defect or error that would significantly increase the current draw. The GBC can handle higher currents much better than the DMG (or the GBP which is the worst in that regard) and I assume that the SP should be be similar to the GBC in that regard.

Do you have a multimeter with which you can measure the resistance of R8 and R9? Those are a voltage divider to split the 5V from the cartridge to 3.3V so the rp2040 can detect if the Game Boy is turned on. They should be 5.5kOhm in total, so there is not much current flowing that would burden the Game Boy. But if for some reason they picked the wrong resistors here, that current might be much higher - too much for the DMG, but managable for the GBC.

So, if you measure the resistance across the outer ends of R8 and R9 together you should see 5.5kOhm (2.2kOhm just for R8 and 3.3kOhm for R9). If it is significantly lower that might be the problem.

Well, it is a rather wild hypothesis...

Megabusterretro, 2023-02-28:
Just rung the two out and they are reading 3.3 and 2.2 respectively unfortunately.

Megabusterretro, 2023-03-01:
I submitted a ticket with JCLPCB last night as well so hopefully they can figure out something

Megabusterretro, 2023-03-02:
Another update!  Looks like this is not working on a Game Boy Pocket either.

Staacks, 2023-03-03:
> Another update! Looks like this is not working on a Game Boy Pocket either.

That does not really surprise me. If whatever causes the problem triggers a reboot because it drains too much power, then the GBP is the first one to go, because in my experience with the Wifi cartridge it is the worst in handling power spikes.

Megabusterretro, 2023-03-03:
So I am working with JCLPCB but in the meantime I am going to double check my work and make sure it isnt just a bad soldering job on my part.  If it were something with how I was soldering the pins, which pins should I focus my attention on?

Staacks, 2023-03-03:
I don't think that a soldering error would be selective to the DMG and GBP. If data pins or address pins were affected you would not see the Nintendo logo (except maybe for some of the higher address pins, but those would cause problems on the GBC eventually). You also would not see the Nintendo logo if 5V, CLK or GND were not connected and other non-connected pins would either mean it always works (maybe no savegames with nWR) or the Nintendo logo would not work.

Shorted pins might be more interesting as some rare combinations of pin uses could lead to a short then, but I do not see any combination that would not also cause trouble for the logo or the GBC. The only interesting one might be the nRST pin, but again: Why would that not be a problem for the GBC.

I am thinking that turning on the ble LED somehow might trigger the problem. That would at least explain why it happens in that exact moment, but then again there are several things happening in that moment. Does anything happen if you press the mode button while the Nintendo logo ist still crawling down? That button also connects the LED to ground turning it on - that's not the same as turning on the LED with the rp2040, but maybe something happens in that case...?

Megabusterretro, 2023-03-06:
@Staacks Mystery Solved.

I am a novice at soldering and I decided I wanted to use flux to give me less change of bridging contacts while soldering the 32 pin connector.  I guess on my first three from my second batch didnt burn off all of the flux I used and it was causing a connection issue.  I have done 6 more without flux and they work like a charm.  I also went back to a couple that were only working on the GBC/GBA and reflowed all the contacts and made sure I burnt off the rest of the flux and they started working.

Thanks for all of your responses....this has been a huge learning experience for me.

Closed 2023-03-06.

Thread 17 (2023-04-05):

60fps output idea by 8x scaled Motion JPEG

Ikadzuchi, 2023-04-05:
Hi.
I read that you tried Motion JPEG and it's too heavy.
Then, how about enlarging the image 8 times?
In JPEG, images in 8x8 px units are encoded only with DC components. Encoding can be done in pixel by pixel, with only lightweight operations like subtraction, table lookup and bit operations.
As of compression rate:
Setting quantization table to all 0xFF and the DC component will be in the range of -4 to +4 (enough for 4 shades),
then difference in range -8 to +8, and by limiting it to -7 to +7, only 0 to 3 bits are required for encoding each number.
By assigning Huffman codes as 3, 2 and 1 bit ones for the 0, 2, 3 bit number, 1 block (= original 1 pixel) can be represented in 4 or 3 bits.
With 1 bit for AC component (it is “all 0”), compression ratio of 5 bits/pixel will be possible.
I don’t know much about Motion JPEG, but I think this may be a feasible idea.
See the sample image file (made with GIMP). Note that however, the Huffman table is not assigned as described above. (Because  it was difficult to create such a file.) It's optimal assignment for this image, not for minimizing worst case size.

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

Staacks, 2023-04-10:
Sorry for the late reply - I have been on vacation.
I must say that I love the idea, but I have to admit that I only know the principle of how jpeg works. When I tried it, I used a library and hacked away at it to improve speed and take some shortcuts, but eventually gave up because the difference between required speed and what computation power I had to spare seemed insurmountable.

Your idea indeed sounds like there would be very little overhead and in context of USB Video there is not more to Motion JPEG than defining the correct USB descriptors and sending a series of JPEGs (if I am not forgetting something).

However, it will be a while before find the time to look into the details of an actual jpeg implementation and testing it. I am currently working on an entirely different project (deadline in about two weeks and I would like to make a Youtube video on the results) and I have a few other things on my list for the Interceptor that require less learning / research. But I will look into this for sure!

Staacks, 2023-06-17:
It's working!

https://twitter.com/diconx/status/1670186665845874700

Still quite a few things to do before I can commit a proper test version:
- Status screens in JPEG
- OSD is currently not working because I start the JPEG conversion while drawing the lines. Only option might be to draw directly onto the finished JPEG, which should be possible because the pixels are now indeed perfectly aligned in 5bit blocks. Using the differential encoding, it might even be easier to just shift the brightness of a range to achieve a semi-transparent effect.
- There are a few glitches while restarting games and such

The great thing is that I managed to offload the encoding almost entirely from the CPU to the rp2040's PIOs and chained DMA channels.

Oh, and it also resolves the Mac incompatibility issue (#1). This is such a massive improvement to the GB Interceptor. Thank you so much for this ingenious idea!

Ikadzuchi, 2023-06-18:
Great!
I'm happy that my idea was incorporated into your great work. (and sorry for not replying...)
I hadn’t thought about the blending. Encoding 0x03, 0x02, 0x01 and 0x00 with fixed 5 bits sounds good. I don't see any downside in it either.
It’s great that offloading to peripherals has become possible.

Staacks, 2023-07-04:
Bad news: While MJPEG is generally a sequence of arbitrary JPEGs, the USB Video Class actually is a bit more specific about it and requires chroma channels with 2x subsampling. While some apps are happy with only the luma channel, others (like OBS) refuse to decode the MJPEG stream without chroma. So, I had to add an overhead of almost 3kB per frame and cannot quite reach 60fps any more (it's something around 56fps).

Not sure if I can squeeze out the last few frames. I will have to dive into TinyUSB to fix an issue with its UVC implementation anyway (the remainder of an older frame is transferred after restarting a video stream, breaking restarts in OBS), so maybe I find something to get those few percent that are still missing...

Staacks, 2023-07-27:
Just realized that I might add a little update with good news here:
The current beta (and very likely the official release) of the firmware now allows switching between 30fps mode and 60fps mode. In 30fps mode the Interceptor encodes a JPEG with chroma, which should be compatible with almost any software out there. In 60fps mode the Interceptor ignores chroma and can achieve 60fps. I have made a pull-request that has already been merged into OBS that will support this 60fps mode in the next release of OBS.

Staacks, 2023-08-05:
Just released version [v1.2.0](https://github.com/Staacks/gbinterceptor/releases/tag/v1.2.0) with the feature.

Staacks, 2023-12-20:
@Ikadzuchi Answering here as I am not sure if you got my message on Twitter or if it has been filtered:

I will be giving a talk about the GB Interceptor at the 37c3 ([Chaos Communication Congress](https://en.wikipedia.org/wiki/Chaos_Communication_Congress) - not sure how well known it is outside Germany).
This will also include a section about how MJPEG encoding works on the rp2040 and my plan was to show a screenshot of your initial suggestion from the issue on GitHub. Is there any additional way you would like to be credited for the idea like a real name or handle on another platform?

Ikadzuchi, 2023-12-24:
Oh, your Twitter message was received but apparently not notified. (How annoying Twitter is these days...)
I somewhat know c3. I think I watched some videos of it on YouTube or elsewhere.
I want to be credited as Ikadzuchi (name hear) or 雷更新世/@pleist (name on Twitter).
Thank you.

Staacks, 2023-12-29:
I have placed both on the slide :)
The talk will be today at 20:30 CET and can be seen live at https://streaming.media.ccc.de/37c3/granville. There will be a recording available later at https://media.ccc.de/c/37c3.

Closed 2023-06-18.

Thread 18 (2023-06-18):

NCP1117LPST33T3G Part Shortage/Known Good Replacement

Megabusterretro, 2023-06-18:
@Staacks Hope you are well!

I am trying to buy another run of the GB Interceptors and it looks like
NCP1117LPST33T3G is out of stock and checking DigiKey it seems that the lead time is December.  Is there a possible 1 to 1 replacement of this part?

Hope this is a good platform to asking this question and thanks again for all the work you have done on this!

Staacks, 2023-06-20:
My electronics experience is rather limited in this area. I picked this voltage regulator simply because it was used in the minimal hardware example from the rp2040 documentation. In my wifi cartridge project I used a NCP1117IST33T3G which has a higher dropout voltage, but I think it should work as well - but that is not available either.

I also build one Wifi cartridge with a AP7361C-33ER LDO and it worked fine. At that time I was hoping that it could solve the brown-put problems that I had with the wifi cartridge and while it did not solve it, it seemed to work identical to the NCP1117. And they are available!

Of course, I have not tried them with the Interceptor, so please check the datasheets to see if there are any differences that I did not consider, but I am fairly optimistic that it works. Also make sure that you get the 33E**R** version, because the one without the R has a different pinout and will not be compatible with the PCB.

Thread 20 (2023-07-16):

gb interceptor works in pc but it doesn't recognize the game

ScorpioNMsX, 2023-07-16:
**Type of issue**
gb interceptor works in pc but it doesn't recognize the game
on the screen of the gameboy you can see the incomplete logo, but when you disconnect from the pc it does start correctly
**Describe the bug**
gb interceptor works in pc but it doesn't recognize the game
on the screen of the gameboy you can see the incomplete logo, but when you disconnect from the pc it does start correctly

**To Reproduce**
Steps to reproduce the behavior:
1. Go to '...'
2. Click on '....'
3. Scroll down to '....'
4. See error in logo

**Host software (please complete the following information):**
 - OS: Windows
 - Software: OBS

**Game Boy:**
- Model: gameboy color cgb 001

**Game:**
- Title: [e.g. Tetris]
- Version: [Usually printed on the cartridge, e.g. DMG-ZL-NOE]

**Additional context**
I have assembled all the components myself, could it be an assembly error?

Staacks, 2023-07-17:
To be sure I understood the details correctly: The Nintendo logo on the Game Boy is broken when the Interceptor is used and plugged into a PC. But if you just unplug the USB cable from the PC but the Interceptor is still between the Game Boy and the cartridge, the logo looks fine and the game starts?

That's an odd one, because the Interceptor is designed to not influence the game at all and the contacts of the cartridge should be wired directly to Game Boy. So, normally, if the logo does not work, I would indeed suspect a lose soldering point or a short between two soldering point. However, the state of the USB cable playing a role makes me a bit less confident about that

When you say that you assembled all components yourself, I assume you really mean ALL components, including the rp2040, USB socket, capacitors etc..? Does the Interceptor work on its own? So, can you see the standby screen?

ScorpioNMsX, 2023-07-17:
If correct, the gb interceptor without connecting to the pc without receiving power and inserted in the gameboy works but once connected from the obs the pc detects it and the image of insert game appears. when turning on the gameboy the nintendo logo is corrupted, the game does not start and the obs screen stays waiting for the game.
PS: I have assembled all the components myself including the rp2040 with soldering station. Could it be that some component is not well soldered? but in this case the pc should not detect the gb interceptor?

Staacks, 2023-07-18:
There are many ways thinks can break if there is a bad connection or a sort circuit. I would agree that most would end with the Interceptor not being recognized by the PC at all, but in some cases weird things are possible. For example, if there is a short between an actively driven GPIO output (for example the one that drives the blue LED, although that becomes active after the game has been recognized) and one of the cartridge pins, I would expect the game to fail when that LED turns on, which would only happen when the USB cable is plugged in.

So, that could be a tedious search... Do you have a voltmeter? Could you connect the Interceptor via USB and check if there is a voltage across any of the cartridge pins when it is not plugged into a Game Boy. (Actually, I am not 100% sure if a harmless potential difference is to be expected if the pins are not driven and since I am on vacation I do not have a working Interceptor at hand to compare. Still, it might be interesting if only one pin has a voltage against ground and others don't.)

Oh, and is the broken logo always the same? If so, could you post a photo of it? Maybe this helps figuring a specific pin that is always high or always low.

Staacks, 2023-08-05:
Any news on this? Since I suspect that it is a problem specific to your individual build I would close this for now, but let me know if I can be of any further help and please report back if you find something that might help others.

Closed 2023-08-05.

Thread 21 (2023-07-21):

Feature request - Additional colour palettes.

Widge-5, 2023-07-21:
Hopefully a relatively straightforward feature request (depending on how the colour palette is managed).  Could it be possibly to add alternate colour palettes into the firmware?
As the button on the Interceptor will currently toggle between B&W and Green images, I suggest adding more options for variety of displaying the 4-colour palette of the DMG GameBoy.
I imagine this as being similar to the GameBoy Color's palette selection for classic monochrome games.
I hope that makes sense.

Staacks, 2023-07-22:
Unfortunately, it would not work as flexible as what you are probably hoping for.

Internally the GB Interceptor has to manage three buffers with images: The one it is currently rendering to, the one that has been finishes that is ready to be sent via USB immediately when the next frame is due and the frame that is currently being sent via USB. (The last two cannot be the same because the USB video frame rate is not synchronized to the Game Boy frame rate).

In the upcoming version 1.2.0 with MJPEG support it is actually four buffers, because there is an additional one: One buffer that is currently rendered, one finished image that is currently encoded to JPEG, a JPEG version that is ready to be sent and the buffer that is currently being sent. In this case the latter two are a bit smaller because they are already in JPEG format, but in total it amounts to roughly the same amount of data.

The point in both cases is that these buffers take a lot of RAM and therefore only hold a grayscale component. Also for each processing step the Interceptor only needs to handle a grayscale component. The old NV12 format as well as the new MJPEG format both encode luminosity (grayscale brightness) and chroma (the color information) separately, so the Interceptor only handles luminosity and adds static color information in the very last step. It stores the color information only in the last two buffers and uses the same entry for every single pixel - only changing it once you switch from grayscale to green mode.

All this means is that assigning a specific "hue" to all grayscale pixel (i.e. making them all different shades of the same color) is very easy. Assigning differen colors (like light gray is yellow and dark gray is red) would be extremely difficult or maybe impossible because every buffer would need color info and every processing step needs to handle more data. Maybe we could leave the first buffers grayscale and assign the colors later, but that would mean that the data is no longer written sequentially and cannot be simply handled by a few DMA channels as it is right now.

Oh, also currently the color channels are subsampled by a factor of 2 (again, both in NV12 and MJPEG). This means that a block of four pixels will have to have the same hue anyway.

So: Are you looking for other single-colored options (like red mode in addition to green mode) or a palette option like the GBC provides?

Widge-5, 2023-07-23:
Thank you for the detailed explanation. It does help to understand how the Interceptor works.
My hope was that the Interceptor could give palette options in the same way as the GBC, but it appears that this isn't possible.
If additional single-colour options are added in to a future update then I would welcome that as a bonus. But overall I am very pleased with the Interceptor as it is with it's b&w and green modes.
Thank you for sharing your amazing project with the rest of the world :)

Staacks, 2023-07-25:
Glad you like the project :)
I don't think that I will add more color options, though (would love to add palettes, but that is tricky as mentioned above). Since the Interceptor only has a single button, toggling through multiple options would be a bit annoying when most people are only interested in gray and green. However, this can easily be achieved in OBS with filters.

Closed 2023-07-25.

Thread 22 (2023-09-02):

showed waiting the game.....

hpx1984, 2023-09-02:
Hi Sir

many thanks your hard working on this great project

now i built one and every thing seems good
but i just can saw the screen of "waiting the game....." or "game boy turned off"

where i can check to try to fix this issue?

hpx1984, 2023-09-03:
more information

i can saw the device on PC
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

FW:1.2.0
Turned off GameBoy
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

Turned on Game Boy ,the game boy working as normal but PC screen showed "waiting for game"
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

Interceptor status:
PWR Blue LED on,and another red LED is flash
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

Sir ,any time ,please help me if you got my message and if you have free time

hpx1984, 2023-09-03:
hi Sir

i found the problem is on the flash IC , now fixed the problem and it can working
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

Staacks, 2023-09-04:
Glad you found the problem :)

Closed 2023-09-03.

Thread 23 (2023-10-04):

[Feature Request] GameShark Firmware for Game Boy Screen Recorder

Tom-Neverwinter, 2023-10-04:
Describe the feature
I propose a firmware update or a new firmware module that mimics the functionalities of the GameShark cheat device for the Game Boy series. Given the difficulty of obtaining an original GameShark these days, it would be valuable for many users if the Game Boy screen recorder device, with its RP2040 chip, could also serve as a cheat interface.

Use Case

Insert Game Boy game cartridge into the screen recorder device.
Use the device interface to select desired cheats or input new cheat codes.
Play the game with cheats enabled while also having the ability to record gameplay.
Expected behavior
Once a game is loaded, users should be presented with a list of known cheat codes for that game (if available). Users can toggle cheats on/off or add new ones. Once set, the game should play with the selected cheat functionalities.

Screenshots
While I currently don't have mockup designs, a user interface similar to the original GameShark, but adapted to fit the screen recorder device's display, would be ideal.

Host software (please complete the following information):

OS: All OSs that currently support the screen recorder device (Windows, MacOS, Linux, etc.)
Software: Proprietary software for the Game Boy screen recorder.
Game Boy:

Model: All Game Boy models that are currently compatible with the screen recorder device.
Additional context
The RP2040 chip has the necessary computational power to handle cheat code injections on-the-fly. This would not only serve nostalgia purposes for those who loved the GameShark but would also provide additional utility to the screen recorder device. Furthermore, an added feature could be the ability to take screenshots or record short GIFs using the Game Boy Camera.

Note: This is a hypothetical and generalized feature request. In a real-world scenario, the specifics might need more details, especially technical ones, based on the capabilities and constraints of the device in question.

Staacks, 2023-10-04:
Well, I see how this would be nice, but the GB Interceptor cannot interfere with the game by design. The address and data lines of the cartridge are directly connected to the Game Boy's cartridge slot and the Interceptor can only read the data. Your suggestion requires a different hardware design - i.e. that would be a different device.

Also, it might not be entirely trivial to do this on the rp2040 alone. Using a shared address block (16 GPIO pins), reading/writing data to the cartridge (8 pins) and sending custom responses to the Game Boy (8 pins) use up all GPIO pins and you still cannot check the R/W or CS pins. So, instead you will want to add at least a bus transceiver that allows the rp2040 to disconnect the cartridge whenever the rp2040 should answer (I wouldn't entirely trust overwriting the high address pin for this at such tight timings), but then you would lose the ability to capture the response from the cartridge. Still, it should not be too difficult, but as I said: That's a different device.

Closed 2023-10-04.

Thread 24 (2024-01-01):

Tracking state of DIV register

msinger, 2024-01-01:
Hi, after your amazing presentation on Friday, I asked you about the issues with tracking the value of the DIV register. If I recall correctly, the possible issues are:

* You don't know which value DIV has when the first instruction of the game gets executed, because this is different for each Game Boy model and/or boot ROM version.
* You might not be able to start tracking the DIV register from the very first clock tick after reset, where it will always start at zero, because you might not be quick enough in setting things up.
* When the CPU is in HALT mode, the output of the 1 MiHz phi clock is disabled and you can't keep track of the time anymore.

I'm pretty sure the first two points can be solved. If you're really too slow, then this would require a hardware change. The HALT mode issue will be tricky.

When the Game Boy comes out of reset, it uses the DIV register (the full 16 bit, not only the 8 bit you get access to) to count to 0x8000. It counts with 1 MiHz, so it takes ~32 milliseconds to reach that value. When this value is reached, then the 1 MiHz phi clock that you see on the cartridge port starts ticking. Before that, the phi clock is held high, so you can't actually see the very first rising edge, because it is already "risen". The CPU will fetch the first instruction of the boot ROM two phi ticks after the 0x8000 was reached. Here are two GTKWave screenshots from a simulation of the DMG-CPU B chip, showing this scenario:

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
(DIV starts counting from 0, when low active reset signal is released. "clk" is the 4 MiHz crystal clock. "phi" is the 1 MiHz clock you see on the cartridge.)

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
(1 MiHz phi clock starts ticking after DIV reaches 0x8000 for the first time after reset. CPU fetches first instruction shortly after that. "afer" is the high active synchronous reset signal of the SM83 CPU core. "a" and "d" are the chip internal address and data buses, not visible on the cartridge port.)

So, when you start counting from the very first phi clock tick, you should know the exact value of the 16 bit DIV register as long as there is no HALT instruction used by the game. Register FF04 shows you bits 6-13 of those 16 bits (start counting from 0, not 1). When the game resets DIV by writing to 0xFF04, the whole 16 bits get reset to 0, not only bits 6-13. You should also be able to determine the Game Boy model / boot ROM by counting the number of ticks it takes until it reaches the first instruction of the game.

If you are really to slow after detecting that the Game Boy was switched on, and you are missing the first tick of the phi clock, you could address this in a new hardware revision. I saw that you used up all GPIOs already, so you would need to switch to a bigger microcontroller. You can buy yourself as much time as you need, by just driving the reset pin low. You can't do that with those somthing245 level shifters though. It needs to be done with an open drain output. It would also be beneficial to be able to read the reset line, because cartridges like the EverDrive or the Nintendo GB-memory cartridges that were only available in Japan are also pulling at the reset line to boot into the actual game after it was selected in the menu. I don't know if and how you are handling this right now. There is a transistor that is also used for bidirectionally level shifting I2C buses. It's the BSS138. I use it for the Game Boy reset line like this and it works good:
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

It's too bad that the HALT mode disables the phi clock on the cartridge port. The only solution I see there is to start a timer and measure the time from the HALT instruction until the phi clock is enabled again. The mechanism responsible for generating the 1 MiHz clock from the 4 MiHz is always running internally, only the output is disabled. This means, the timing grid for the 1 MiHz phi clock will be preserved. For example, if phi stops at the 4 MiHz clock tick number 12, it can only resume at clock ticks like 20 or 24 or 28, but not on ticks like 21 or 22, because they are not dividable by four. You could use this information to counter inaccuracies of your locally tracked time while the phi clock is disabled. I don't know how good this would work, but before I heard from you, I wasn't expecting that something like this GB interceptor would work at all. So what do I know...

I was wrong about the boot ROM not using DMA btw. The Game Boy Color boot ROM is using the HDMA. But I didn't understand why this is relevant or if you already talked about something else there.

If you are actually trying to implement accurate DIV tracking in the future, I could help you figuring out the details you need for that.

Staacks, 2024-01-02:
Thanks for all the details. I am not entirely sure why I gave up on this. Maybe I made a mistake or maybe I am forgetting about a problem. Now I am really feeling the itch to give it another shot, but unfortunately after spending a lot of time on the presentation I will have to invest my little free time in a few other projects first (mostly, but not only work and family related). But in a few months, this will be at the top of the list :)

Having a timer during HALT is not an unsolvable problem. In fact, the GB Interceptor already starts an internal timer as a substitute for the external clock to drive the PPU emulation, which does not HALT. However, since it is not so precise to begin with, being off by a few cycles after a long HALT is not much of a problem - especially as it is the less demanding games that tend to pause extensively. I have no idea which precision is possible, but I currently train the internal clock on the external clock that I see during the boot ROM and it should mostly be a matter of throwing enough digits at the problem. Among my worries about the unknown initial state and not knowing the influence of different Game Boy models I always thought that this was rather an inconvenience of restructuring the code...

About the reset line: In the current implementation I do not care about the reset line because I dismiss everything before the game starts and the PIO is observing the clock which is not running before the reset state is lifted. As soon as the GB Interceptor is not following the game anymore (either because the Game Boy was turned off, the clock signal was lost too long or an error was detected) it simply observes the address part of the incoming bus events and waits for 0x0100. This might need some improvement to reset if the clock is lost without ever reaching 0x0100 (for example corrupted Nintendo logo, clean and try again successfully), but I think this should still work reliably.

I have to admit that I am not entirely sure how HDMA behaves. So far I have almost entirely focused on the monochrome stuff. But isn't the GBC's DMA different than the old OAM DMA in that it actually halts the CPU? How does this affect the DIV register?

msinger, 2024-01-02:
Unfortunately, I'm no expert on the GBC, because there aren't any useful die shots of the CGB chips. Yes, according to the pan docs, the HDMA halts the CPU. Now I understand why you are worried about that. I also read that it is not allowed to issue a HALT instruction between the short DMA bursts, when it is used in H-blank mode. I think that the HDMA is halting the CPU in a different way. It wouldn't make any sense to stop the phi clock on the cartridge port while the DMA is issuing read requests on that port. Even if it were stopping the phi clock, the DIV register would keep counting. It never stops, because it is used for generating the clocks for other peripherals, like the timer and APU. (Well, that's not entirely true. If the CPU executes a STOP instruction, then the crystal clock stops, and with it everything else. But I'm sure no game ever uses this useless instruction anyway.)

I will run some tests and inform you about the results.

msinger, 2024-01-02:
Everything is fine, don't worry. There are no gaps in the phi clock during the boot ROM execution on the GBC. I also noticed that directly after power on, the clock is high for ~41 milliseconds. I guess, these are around 9 milliseconds for the power ramping up while the system is under reset, plus the 32 milliseconds that the DIV register needs to count to 0x8000, until the synchronous CPU reset is released as I described above. I measured this some time in the past for the DMG, where the phi clock was high for ~51 milliseconds before it started ticking. So it just takes a bit longer. But doesn't matter. When you see the first rising edge, then the 16 bit DIV register should be at 0x8001 in both cases.

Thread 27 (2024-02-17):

Funnyplaying FPGBC FPGA based Gameboy Color not working

peymanfard, 2024-02-17:
Funnyplaying FPGBC FPGA based Gameboy and GB Color not working
Tested on 0.90 stock firmware, 1.04 firmware and firmware 1.06, with either core (GB and GBC)

Gets stuck on "Waiting for game..." screen

Original GB works ok  (OBS/Windows 11)

Staacks, 2024-02-19:
Interesting, I have never heard of those. Unfortunately, this means that I cannot do much about this at the moment except adding it to the list of incompatible devices. Are there variants or is "Funnyplaying FPGA-based Game Boy" precise enough?

peymanfard, 2024-02-19:
I think so… AFAIK there are two hardware revisions, I’ve tested V1.1

Here it is: https://funnyplaying.com/products/fpgbc-kit

Staacks, 2024-02-20:
ok, thanks, I have added it to the list. Hopefully it falls into my lap one day, so I can check why it isn't working.

But after all I am not that surprised about problems with third-party Game Boy clones as the GB Interceptor interprets a lot of additional stuff visible on the memory bus that the Game Boy technically is not required to expose on the bus. I am still a bit surprised on how close the Analogue Pocket is to the real device with only a small deviation (which I still have to fix, too).

Unessential, 2024-06-05:
I just received an interceptor today (where i love ordering the pcb costs about the same as buying a random assembled one)

Tested it with GBA SP, and my FPGBC.  (GBA SP was a tight fit, didn't want to try my NDS cuz it was even tighter)

If I were to hazard a completely uneducated guess. (I watched your YT video and remember you made some exceptions for problematic syncing). It would be that the FPGBC is known to be inaccurate in terms of speed.

It has several speed settings, and the closest one to actual hardware is slightly too fast. (less than 1%, perceptible from having actual hardware beside it and letting it run the same sequence and seeing the actual hardware fall behind).

The other difference is that the FPGBC uses a custom logo and not the nintendo logo and bypasses the antipiracy with a hack. While that may ALSO interfere with syncing, I loaded mine up with custom firmware that uses the original logo. (was having problem starting GB games with custom palettes with GBC mode because they didn't apply the anti piracy hack for the colour mode changes)

There are other slight inaccuracies that causes some anomalies in certain games, but I doubt those would be distinguishable via a device connected to the cartridge slot...

Unessential, 2024-06-05:
I just remembered that the Super Game Boy also runs fast. but I don't know by how much. Seems like a good way to test my theory to see if i'm on track. Gonna pull that out, and see if the game syncs.

Staacks, 2024-06-05:
Thanks for your thought. Since I do not have that system, I can only speculate, but here is what I think:

**Speed**

The Interceptor can indeed get into trouble if the system is running too fast, simply because at some point the rp2040 cannot keep up. This, however, depends on the sequence of commands that the Game Boy executes. Some of the Game Boy's CPU instructions are very easy to emulate and others take many more cycles for the rp2040. In some cases this indeed is really close to the limit and I would not rule out that 1% could push it over the edge, but this would then be a problem in specific games or specific situations of a game where the Interceptor would be thrown of. I do not think that 1% would throw it off entirely.
Besides, as you mentioned, the Super Game Boy works fine.

**Custom logo**

This is actually the reason that the Interceptor does not have a problem with different speeds as long as it does not get too fast. It uses the clock signal during the start to measure the speed of the device. So, while the Game Boy is busy showing the logo, the Interceptor only builds a little statistic about the ratio of its own clock and the Game Boy's clock. It only starts to worry about the actual instructions when the Game Boy requests the starting address of the game. At that point the logo is gone, so the Interceptor does not really care about what is going on before that. It might only be a problem if there was no clock signal at all during the boot sequence, which is only possible if the device does not even do the logo check. (Not entirely sure why they even need to circumvent any anti piracy, tbh. A simple ROM game should not care about the order data is requested. Are there games that check if the logo check has been made?)

**The issue with the Analogue Pocket**

So, instead I think that it is simply not sending the stuff to the cartridge that does not have to be sent there to begin with. From a technical point of view, the Game Boy only needs to set the pins of the cartridge if it needs to read/write from/to the cartridge. For any operation involving the Game Boy's internal RAM, VRAM, I/O etc. there is no need to disclose any of this to the cartridge. It should probably keep the clock signal active and make sure that the address pin and or CS pin are set such that the cartridge knows that it is not being addressed, but that's it.

But the original Game Boys reveal much more. The cartridge gets the full address of every operation even if it is not targeting the cartridge. This includes addresses for code that is executed from RAM (most of the time) or the address of the stack pointer during function calls. The Interceptor relies on those for some edge cases (like telling a function call to an interrupt address from an actual interrupt) and will assume an error state if it does not see those.

As mentioned above, I was quite impressed to see all these details on the bus in case of the Analogue Pocket. It just shows the stack pointer addresses on cycle earlier (or was it later) than the original hardware. I can see why the original Game Boys would reveal them, but for a modern system that just emulates this behavior, there is no reason to do it this way, especially as I do not think that there is any other application or special cartridge that would need this behavior. So, I think the Funnyplaying FPGA system just reads the cartridge instead of replicating the entirely unnecessary extra info on the memory bus - or if it does replicate the rest, there simply is a little deviation.

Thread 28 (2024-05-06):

Windows Camera photo mode doesn't work but video does

Butterscotch96, 2024-05-06:
**Describe the bug**
Not sure if host software issues count as bugs but it's worth a shot. I want to use the Interceptor to easily get photos off my Gameboy Camera and I thought a good way to do that is to use the Windows Camera app. Videos work just fine but photo is just a blank screen.

**To Reproduce**
Steps to reproduce the behavior:
1. Use Interceptor like normal
2. Open Windows Camera
3. Select photo
4. See blank screen

**Expected behavior**
It should show up like normal but obviously a blank screen isn't normal.

**Screenshots**
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

**Host software (please complete the following information):**
 - OS: Windows 10
 - Software: Windows Camera

**Game Boy:**
- Model: AGS-001

**Game:**
- Title: Gameboy Camera
- Version: Can't find it sorry TwT

**Additional context**
I'm a nerd

Staacks, 2024-05-07:
Without any testing I would suspect that this is because the GB Interceptor does not implement the still image capture feature of the USB Video Class. Since the MJPEG stream is already lossless and since it already represents the full resolution of the Game Boy, still image capture is not really needed. For normal cameras it is used to obtain a single image with a higher resolution / better quality than the video stream, but for the GB Interceptor any frame from the video stream already has the maximum resolution and quality.

However, I will leave this open as a) I am not 100% sure that this is the reason for the problem (I would have expected that the preview would at least show up) and b) I can see how having a still image option might be convenient in some cases. Unfortunately, I do not see that I will find the time to look into this any time soon.

Butterscotch96, 2024-05-13:
What I did for now is I did a short video and then just used a random website to get all the frames as PNGs. Takes a while but works fine.

Unessential, 2024-06-14:
This might be related:

Even though all my laptop ports are supposedly USB 3.2 I found that one port had excessive audio delay when on vlc and obs couldn't capture at all.  (i'm on linux though).  switching to another  port worked for me. I suspect it's a power issue. since it should work with usb 2.0 right?

are you using any usb hubs? Are you on a desktop? or laptop?

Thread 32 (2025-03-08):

Add optional PCB connection between GPIO0 and GPIO1 to facilitate use with Dr Gusman's Logic Analyzer

nitro2k01, 2025-03-08:
This feature request requires some background. Ever since I got my GB Interceptor I've had the idea that it could also be useful as a logic analyzer for the GB CPU bus. The other day I found [Dr Gusman's Logic Analyzer](https://github.com/gusmanb/logicanalyzer) which is a Raspberry Pi Pico logic analyzer project. I tried it with the GB Interceptor and it worked... almost. Two things were wrong.
1) Dr Gusman's firmware only supported 24 channels, whereas there are 28 useful channels of information. I sent a feature request and I'm now working with him now to get this supported, so that should be finished soon.
2) His project is using two separate PIO state machines to capture the data and generate trigger data for complex trigger setups. The PIOs can't communicate directly, so he's using a hack where two digital IOs are connected on the board to pass the signal out and then back in again. (This is also used for chaining devices in his setup.) So to make full use of his firmware, you would need to connect those two pins together.

So, looking at how GPIO0 and GPIO1 are used in the GB Interceptor to see if they could be safely connected to each other, and driven low/high for triggering:
**GPIO0:** Used as power sense for the GB. Connected through a voltage divider using 2.2k and 3.3k. Driving the middle of the divider to 0 V would produce a 1.5 mA current from the GB's Vcc. Driving this to 3.3 V would produce some similarly small current. This doesn't hurt either the IO pin or GB.
**GPIO1:** Used for an LED from Vcc, and a button to ground. Driving this to 0 V is the normal state and lights up the LED. No issue. Driving it to 3.3 V would turn off the LED, but there's one hazard here. Pressing the button in this state would short 3.3 V to ground and potentially damage the GPIO pin. A logic high is output by GPIO0 to signal a complex trigger event, so pressing the button while such an event happens would be a bad idea. But you could also... just not do that.

Connecting GPIO0 and GPIO1 together would also obviously interfere with the original function of the pins, but would 100% safe (as in permanent component damage) when the pins are configured as a GB Interceptor, and "95% safe" when configured as Dr Gusman's Logic Analyzer.

I've HW modded my Interceptor, and this is what I came up with, see image. I confirmed that the mod works with the logic analyzer firmware. I cut out pads in the ground place for a pin header strip used for choosing the mode with a jumper. So, what I'm requesting in the end for a future board version is a similar set of pads for connecting GPIO0 and GPIO1 using something like pin header like shown here, or maybe a small sliding switch. Just anything to make the mode a little easier if you would choose to make it. 99% of people would have no use for it. That's ok, and in this case this would just be two unpopulated pads on the board, that don't do anything.

I'll also mention in passing that while looking at the schematic, I noticed that the +5V trace is the same minimum size as the signal traces. I would personally have beefed that up. But that's a different issue.

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

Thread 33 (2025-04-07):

Question: would be possible to intercept high ram writes?

odelot, 2025-04-07:
Hi! I am the developer of the NES RetroAchievements Adapter. It brings internet and achievements to the real hardware https://github.com/odelot/nes-ra-adapter.

Your way to intercept the BUS was an inspiration and indicate that I probably was on the right track when I tried to intercept memory writes with the PIO. Great work you did. Thank you for sharing all of this.

Which bring us to the Gameboy. I made a quick PoC to test the approach on gameboy and it worked very well (https://youtu.be/6lw4mGO8Hv80) to intercepts memory writes on the working RAM.

The problem is the RA developers uses a lot of memory information from high ram to design their achievements. And this memory is not exposed on the cartridge slot / external bus.

The question is: do you think it would be possible to intercept the high ram writes? It seems you are intercepting the op codes from the game rom, is that right? Would be possible to use the same approach for storages on the high ram?

Thanks in advance.

Staacks, 2025-04-07:
Oh, that's a very cool project!

So, your problem is that you do not do the entire process of observing CPU instruction like the Interceptor does and therefore you need to observe RAM writes directly? Immediately I see two possible problems:
- This will fail during DMA as you will only see the DMA reads on the external bus. However, for classical Game Boy games this should not be a big problem. Most just keep the CPU in an idle loop during DMA and the few that actually use the time tend to read values from HRAM in order to write to some registers. The CPU barely ahs access to anything during DMA, so I would not expect anything relevant to your project. However, if you also want to do this for Game Boy Color games, things might be different. The GBC has more  DMA operations which might make it more relevant to use the DMA time. But since the Interceptor does support color mode, I did not look into color games much and cannot say if it might be a common problem there.
- I do not think that the data is visible even without DMA. Unfortunately, it has been a while since I worked on these details for the GB Interceptor, so I am not 100% sure, but if I remember correctly, the address lines on the external bus tend to match the internal bus activities, but the data lines don't do anything. There is no need to drive the external lines during internal access, so seeing anything there is a byproduct of an electrical design that does not care what's on the bus as long as the highest address bit tells the module to ignore it. In fact, at some point I used the address line state during internal access instead of the address pointer of my register clone as I thought it should be more reliable, but then I removed this as it turned out that one of the Game Boys (I think it's the DMGs) does not always set these lines properly. So, at the very least, if internal RAM data is visible on the external bus at all, you will have to check this for different Game Boy models.

[This page](http://iceboy.a-singer.de/doc/mem_patterns.html) also suggests that the data pins are not driven during internal access (except for a glitch). It says that they are only driven if the read line is high, regardless of CS and write, and that is not the case for internal access. So, to me it looks like the only way is to do the whole GB Interceptor thing and follow CPU instructions to get RAM data. (Well, you can ignore VRAM and do not have to emulate the PPU.)

odelot, 2025-04-07:
Thank you for the ultra-fast reply.

I did this Game Boy PoC during one day, using all I have already done for NES. I didn't logic analyzed the signals or anything. BUT I read this page you shared and could test and verify the behavior described: I could capture the HRAM address but not the value (or not the value I was expecting).

After I finish my NES project, I will try to debug your approach of intercepting the CPU instructions to interpret the RAM writes. (this sound like using a bazooka to kill a fly just because of 127 bytes of HRAM, but maybe it will be the only way)

Thank you very much for your time! If you want to join in during the effort to make a GB adapter, please let me know.

I am not sure exactly how you rolled your project out, but it is being hard to people understand the open-source origins of mine. I often cite your project (and open source cart reader) as an example of how a project like mine can reach the potential users in the future.

I will close the issue, thanks again.

odelot, 2025-04-07:
I am already just looking for memory addresses that are related to achievements. It is usually ~30 addresses. I transfer the data from the bus using DMA to a ping pong buffer, but almost like if it was a logic analyser. When I detect the value is stable, I test if the address is an address of interest and send it to the other core, that process all the RetroAchievements logic (using their lib, the same the emulator uses).

I am also pushing pico to its limit in terms of clock (started with 250Mhz, but now I dropped to 200Mhz) and RAM (unfortunately I need ~32kb for receiving the achievement list from RA - I could optimize it a lit bit transforming all my buffers in dynamic memory and just allocate them as needed - since this huge json is just important in the beginning of the process, before I start monitoring the BUS).

I will study your code to understand how it handles the writes on HRAM and WRAM. It is not clear to me yet if you simulate the CPU and its registers to know the value it would write to the memory.

about the opensource part, it was not a question, it was just me venting out lol.... don't worry about that.

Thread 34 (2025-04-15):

Does it also support audio capture?

Videogamer555, 2025-04-15:
For this to work, it would need to report itself as a Composite USB device, and then expose both Video and Audio interfaces, so that the computer it is plugged into would be able to access both the video and audio streams. Does your device do this?

Staacks, 2025-04-15:
For this to work I need to figure out how to emulate the four audio channels with the remaining resources of an already heavily overclocked rp2040 that even has  its PIOs working almost full time. The USB stuff should be trivial...

So, nope, audio capture is not supported. I have a note on my todo list to play with it at some point as I actually expect implementing the audio part should be fun, but at the moment I don't have time for it and I am very skeptical if it is possible with the current hardware of the Interceptor.

Closed 2025-04-15.

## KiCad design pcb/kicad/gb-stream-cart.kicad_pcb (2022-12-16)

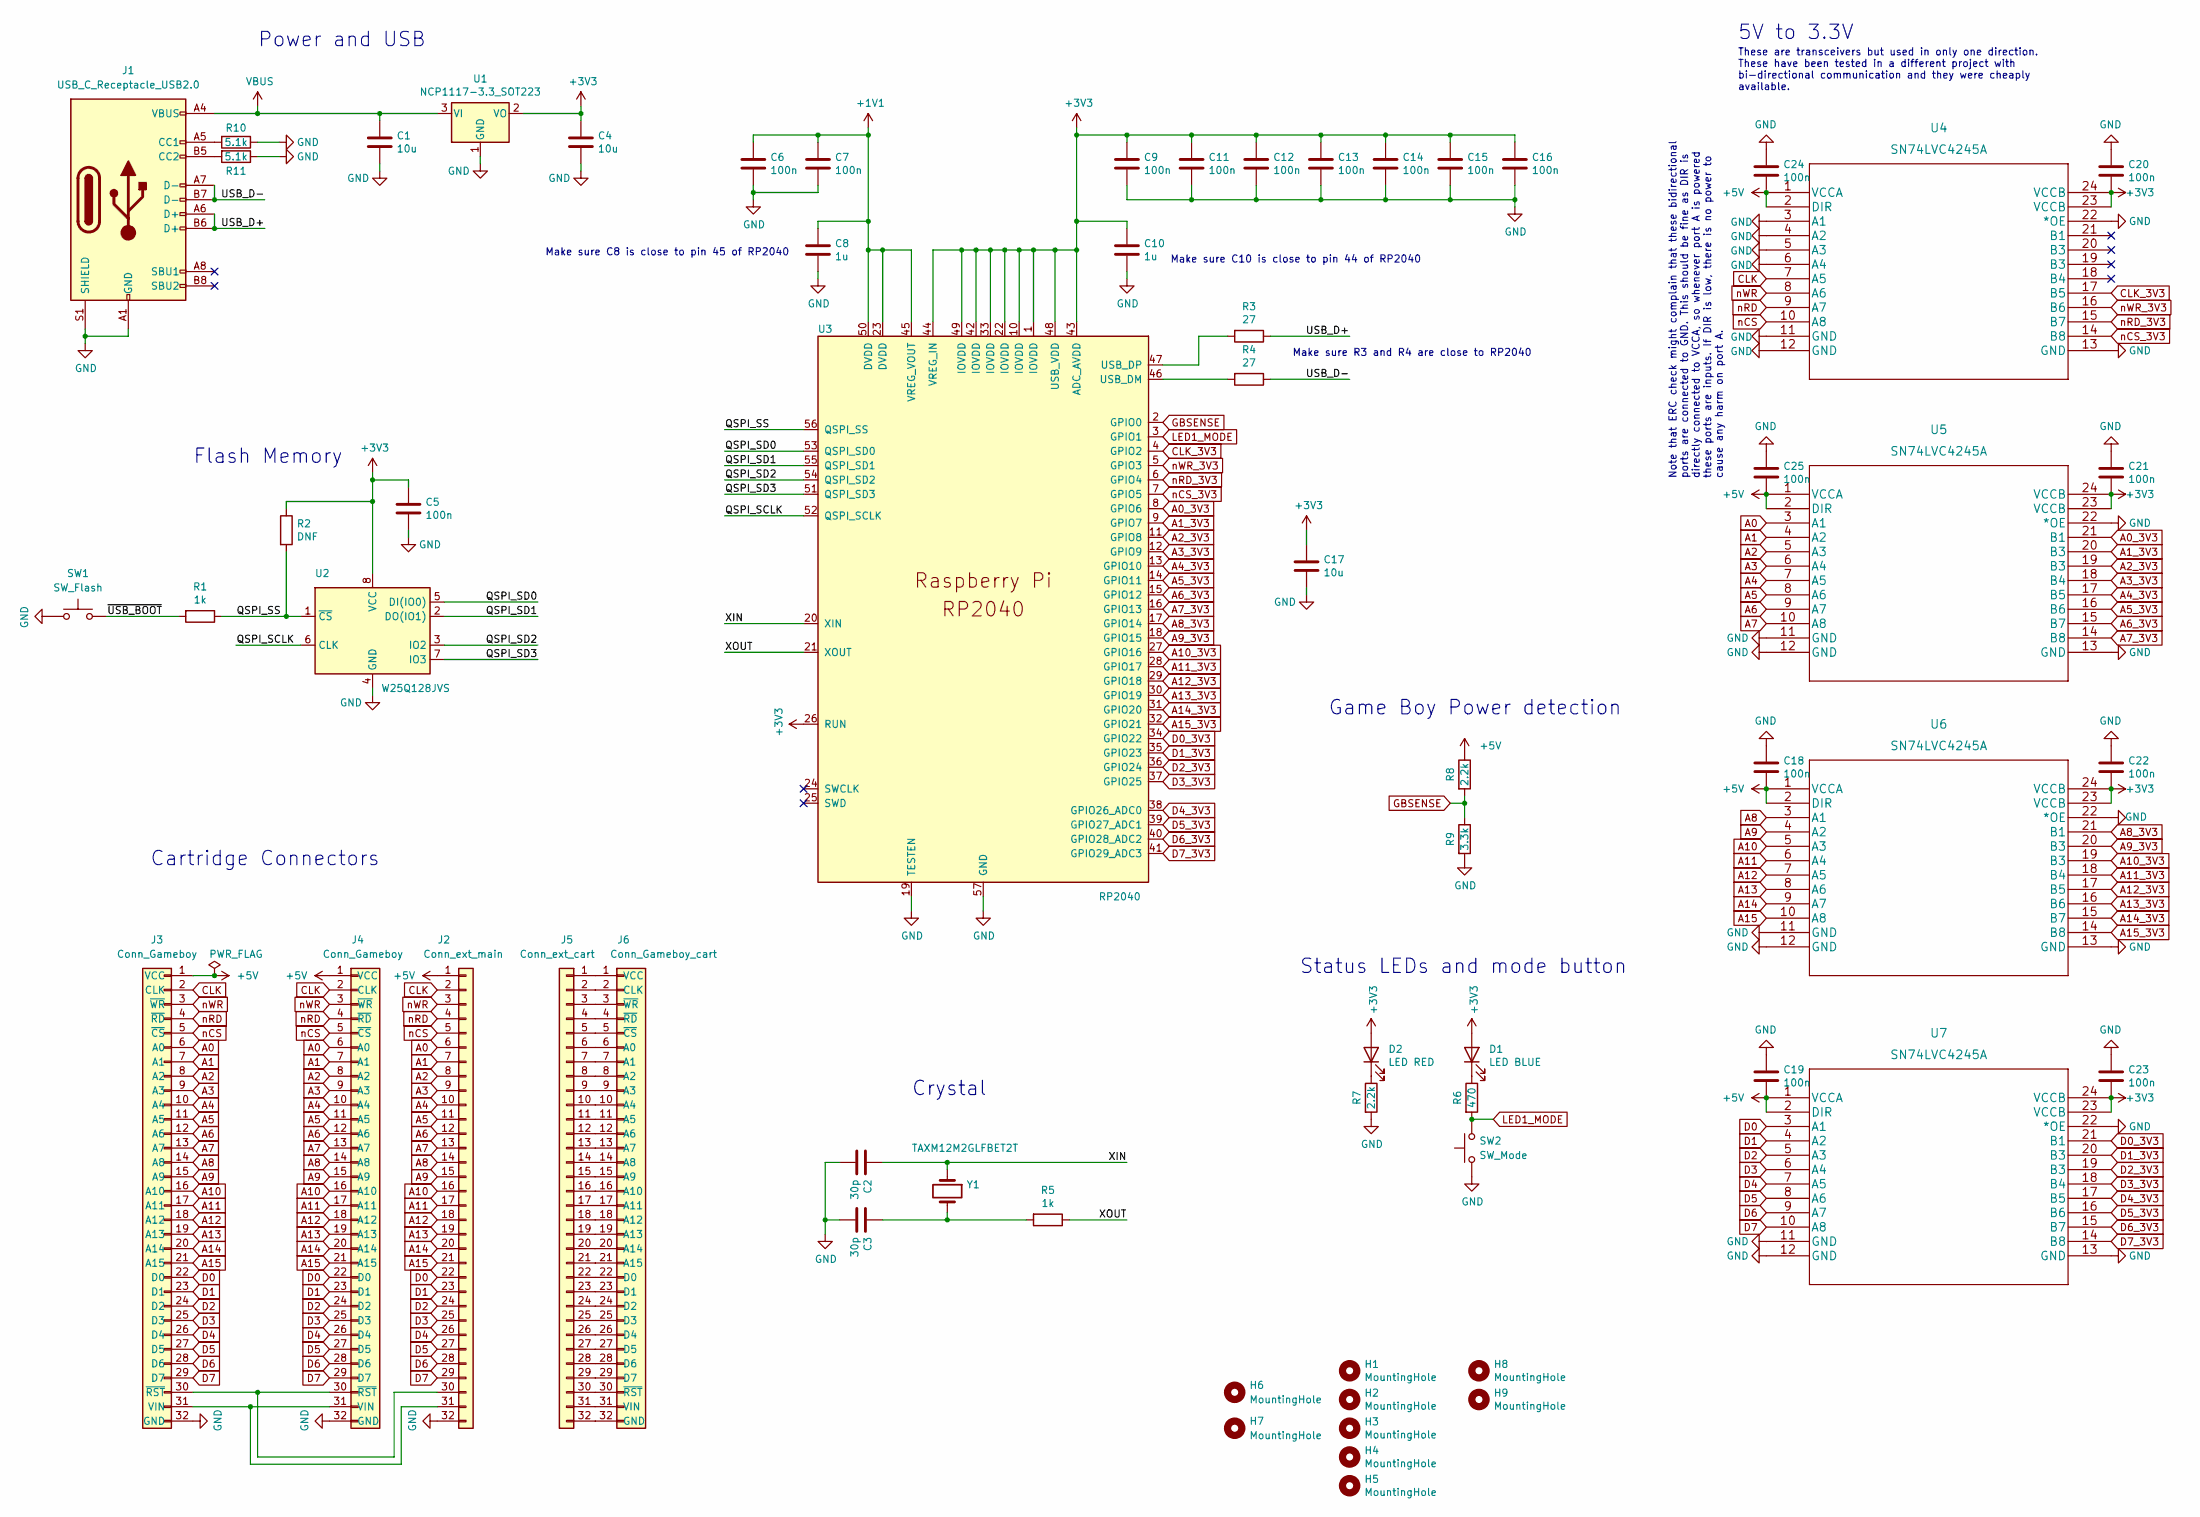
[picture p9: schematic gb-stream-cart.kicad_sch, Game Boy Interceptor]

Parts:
C1, C4, C17: 10u; C_0805_2012Metric; LCSC C440198
C2, C3: 30p; C_0402_1005Metric; LCSC C1570
C5, C6, C7, C9, C11, C12, C13, C14, C15, C16, C18, C19, C20, C21, C22, C23, C24, C25: 100n; C_0402_1005Metric; LCSC C1525
C8, C10: 1u; C_0402_1005Metric; LCSC C52923
D1: LED BLUE; LED_1206_3216Metric; LCSC C130717
D2: LED RED; LED_1206_3216Metric; LCSC C84270
H1, H2, H3, H4, H5, H8, H9: MountingHole; MountingHole_2.7mm_M2.5
H6: MountingHole; MountingHole_8.4mm_M8
H7: MountingHole; MountingHole_2.2mm_M2
J1: USB_C_Receptacle_USB2.0; USB_C_Receptacle_HRO_TYPE-C-31-M-12; LCSC C165948
J2: Conn_ext_main; PinHeader_2x16_P2.54mm_Horizontal
J3: Conn_Gameboy; cartridge_PCBedge
J4: Conn_Gameboy; cartridge-slot
J5: Conn_ext_cart; PinHeader_2x16_P2.54mm_Horizontal
J6: Conn_Gameboy_cart; cartridge-slot
R1, R5: 1k; R_0402_1005Metric; LCSC C11702
R2: DNF; R_0402_1005Metric
R3, R4: 27; R_0402_1005Metric; LCSC C25100
R6: 470; R_0402_1005Metric; LCSC C25117
R7, R8: 2.2k; R_0402_1005Metric; LCSC C25879
R9: 3.3k; R_0402_1005Metric; LCSC C25890
R10, R11: 5.1k; R_0402_1005Metric; LCSC C25905
SW1: SW_Flash; SW_Push_1P1T-SH_NO_CK_KMR2xxG; LCSC C72443
SW2: SW_Mode; SW_Push_1P1T-SH_NO_CK_KMR2xxG; LCSC C72443
U1: NCP1117-3.3_SOT223; SOT-223-3_TabPin2; LCSC C146799
U2: W25Q128JVS; SOIC-8_5.23x5.23mm_P1.27mm; LCSC C97521
U3: RP2040; RP2040-QFN-56; LCSC C2040
U4, U5, U6, U7: SN74LVC4245A; SN74LVC4245APWR; LCSC C7859
Y1: TAXM12M2GLFBET2T; Crystal_SMD_HC49-US; LCSC C111117

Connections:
+1V1: C6.1, C7.1, C8.1, U3.23 (DVDD), U3.45 (VREG_VOUT), U3.50 (DVDD)
+3V3: C4.1, C5.1, C9.1, C10.1, C11.1, C12.1, C13.1, C14.1, C15.1, C16.1, C17.1, C20.2, C21.2, C22.2, C23.2, D1.2 (A), D2.2 (A), R2.1, U1.2 (VO), U2.8 (VCC), U3.1 (IOVDD), U3.10 (IOVDD), U3.22 (IOVDD), U3.26 (RUN), U3.33 (IOVDD), U3.42 (IOVDD), U3.43 (ADC_AVDD), U3.44 (VREG_IN), U3.48 (USB_VDD), U3.49 (IOVDD), U4.23 (VCCB), U4.24 (VCCB), U5.23 (VCCB), U5.24 (VCCB), U6.23 (VCCB), U6.24 (VCCB), U7.23 (VCCB), U7.24 (VCCB)
+5V: C18.2, C19.2, C24.2, C25.2, J2.1, J3.1 (VCC), J4.1 (VCC), R8.1, U4.1 (VCCA), U4.2 (DIR), U5.1 (VCCA), U5.2 (DIR), U6.1 (VCCA), U6.2 (DIR), U7.1 (VCCA), U7.2 (DIR)
/QSPI_SCLK: U2.6 (CLK), U3.52 (QSPI_SCLK)
/QSPI_SD0: U2.5 (DI(IO0)), U3.53 (QSPI_SD0)
/QSPI_SD1: U2.2 (DO(IO1)), U3.55 (QSPI_SD1)
/QSPI_SD2: U2.3 (IO2), U3.54 (QSPI_SD2)
/QSPI_SD3: U2.7 (IO3), U3.51 (QSPI_SD3)
/QSPI_SS: R1.1, R2.2, U2.1 (~CS), U3.56 (QSPI_SS)
/USB_D+: J1.A6 (D+), J1.B6 (D+), R3.1
/USB_D-: J1.A7 (D-), J1.B7 (D-), R4.1
/XIN: C2.1, U3.20 (XIN), Y1.1
/XOUT: R5.1, U3.21 (XOUT)
/~USB_BOOT: R1.2, SW1.2
A0: J2.6, J3.6 (A0), J4.6 (A0), U5.3 (A1)
A0_3V3: U3.8 (GPIO6), U5.21 (B1)
A1: J2.7, J3.7 (A1), J4.7 (A1), U5.4 (A2)
A1_3V3: U3.9 (GPIO7), U5.20 (B3)
A2: J2.8, J3.8 (A2), J4.8 (A2), U5.5 (A3)
A2_3V3: U3.11 (GPIO8), U5.19 (B3)
A3: J2.9, J3.9 (A3), J4.9 (A3), U5.6 (A4)
A3_3V3: U3.12 (GPIO9), U5.18 (B4)
A4: J2.10, J3.10 (A4), J4.10 (A4), U5.7 (A5)
A4_3V3: U3.13 (GPIO10), U5.17 (B5)
A5: J2.11, J3.11 (A5), J4.11 (A5), U5.8 (A6)
A5_3V3: U3.14 (GPIO11), U5.16 (B6)
A6: J2.12, J3.12 (A6), J4.12 (A6), U5.9 (A7)
A6_3V3: U3.15 (GPIO12), U5.15 (B7)
A7: J2.13, J3.13 (A7), J4.13 (A7), U5.10 (A8)
A7_3V3: U3.16 (GPIO13), U5.14 (B8)
A8: J2.14, J3.14 (A8), J4.14 (A8), U6.3 (A1)
A8_3V3: U3.17 (GPIO14), U6.21 (B1)
A9: J2.15, J3.15 (A9), J4.15 (A9), U6.4 (A2)
A9_3V3: U3.18 (GPIO15), U6.20 (B3)
A10: J2.16, J3.16 (A10), J4.16 (A10), U6.5 (A3)
A10_3V3: U3.27 (GPIO16), U6.19 (B3)
A11: J2.17, J3.17 (A11), J4.17 (A11), U6.6 (A4)
A11_3V3: U3.28 (GPIO17), U6.18 (B4)
A12: J2.18, J3.18 (A12), J4.18 (A12), U6.7 (A5)
A12_3V3: U3.29 (GPIO18), U6.17 (B5)
A13: J2.19, J3.19 (A13), J4.19 (A13), U6.8 (A6)
A13_3V3: U3.30 (GPIO19), U6.16 (B6)
A14: J2.20, J3.20 (A14), J4.20 (A14), U6.9 (A7)
A14_3V3: U3.31 (GPIO20), U6.15 (B7)
A15: J2.21, J3.21 (A15), J4.21 (A15), U6.10 (A8)
A15_3V3: U3.32 (GPIO21), U6.14 (B8)
CLK: J2.2, J3.2 (CLK), J4.2 (CLK), U4.7 (A5)
CLK_3V3: U3.4 (GPIO2), U4.17 (B5)
D0: J2.22, J3.22 (D0), J4.22 (D0), U7.3 (A1)
D0_3V3: U3.34 (GPIO22), U7.21 (B1)
D1: J2.23, J3.23 (D1), J4.23 (D1), U7.4 (A2)
D1_3V3: U3.35 (GPIO23), U7.20 (B3)
D2: J2.24, J3.24 (D2), J4.24 (D2), U7.5 (A3)
D2_3V3: U3.36 (GPIO24), U7.19 (B3)
D3: J2.25, J3.25 (D3), J4.25 (D3), U7.6 (A4)
D3_3V3: U3.37 (GPIO25), U7.18 (B4)
D4: J2.26, J3.26 (D4), J4.26 (D4), U7.7 (A5)
D4_3V3: U3.38 (GPIO26_ADC0), U7.17 (B5)
D5: J2.27, J3.27 (D5), J4.27 (D5), U7.8 (A6)
D5_3V3: U3.39 (GPIO27_ADC1), U7.16 (B6)
D6: J2.28, J3.28 (D6), J4.28 (D6), U7.9 (A7)
D6_3V3: U3.40 (GPIO28_ADC2), U7.15 (B7)
D7: J2.29, J3.29 (D7), J4.29 (D7), U7.10 (A8)
D7_3V3: U3.41 (GPIO29_ADC3), U7.14 (B8)
GBSENSE: R8.2, R9.1, U3.2 (GPIO0)
GND: C1.2, C2.2, C3.2, C4.2, C5.2, C6.2, C7.2, C8.2, C9.2, C10.2, C11.2, C12.2, C13.2, C14.2, C15.2, C16.2, C17.2, C18.1, C19.1, C20.1, C21.1, C22.1, C23.1, C24.1, C25.1, J1.A1 (GND), J1.A12 (GND), J1.B1 (GND), J1.B12 (GND), J1.S1 (SHIELD), J2.32, J3.32 (GND), J4.32 (GND), R7.2, R9.2, R10.1, R11.1, SW1.1, SW2.1, U1.1 (GND), U2.4 (GND), U3.19 (TESTEN), U3.57 (GND), U4.3 (A1), U4.4 (A2), U4.5 (A3), U4.6 (A4), U4.11 (GND), U4.12 (GND), U4.13 (GND), U4.22 (*OE), U5.11 (GND), U5.12 (GND), U5.13 (GND), U5.22 (*OE), U6.11 (GND), U6.12 (GND), U6.13 (GND), U6.22 (*OE), U7.11 (GND), U7.12 (GND), U7.13 (GND), U7.22 (*OE)
LED1_MODE: R6.2, SW2.2, U3.3 (GPIO1)
unnamed: C3.1, R5.2, Y1.2
unnamed: D1.1 (K), R6.1
unnamed: D2.1 (K), R7.1
unnamed: J1.A5 (CC1), R10.2
unnamed: J1.B5 (CC2), R11.2
unnamed: J2.30, J3.30 (~RST), J4.30 (~RST)
unnamed: J2.31, J3.31 (VIN), J4.31 (VIN)
unnamed: J5.1, J6.1 (VCC)
unnamed: J5.2, J6.2 (CLK)
unnamed: J5.3, J6.3 (~WR)
unnamed: J5.4, J6.4 (~RD)
unnamed: J5.5, J6.5 (~CS)
unnamed: J5.6, J6.6 (A0)
unnamed: J5.7, J6.7 (A1)
unnamed: J5.8, J6.8 (A2)
unnamed: J5.9, J6.9 (A3)
unnamed: J5.10, J6.10 (A4)
unnamed: J5.11, J6.11 (A5)
unnamed: J5.12, J6.12 (A6)
unnamed: J5.13, J6.13 (A7)
unnamed: J5.14, J6.14 (A8)
unnamed: J5.15, J6.15 (A9)
unnamed: J5.16, J6.16 (A10)
unnamed: J5.17, J6.17 (A11)
unnamed: J5.18, J6.18 (A12)
unnamed: J5.19, J6.19 (A13)
unnamed: J5.20, J6.20 (A14)
unnamed: J5.21, J6.21 (A15)
unnamed: J5.22, J6.22 (D0)
unnamed: J5.23, J6.23 (D1)
unnamed: J5.24, J6.24 (D2)
unnamed: J5.25, J6.25 (D3)
unnamed: J5.26, J6.26 (D4)
unnamed: J5.27, J6.27 (D5)
unnamed: J5.28, J6.28 (D6)
unnamed: J5.29, J6.29 (D7)
unnamed: J5.30, J6.30 (~RST)
unnamed: J5.31, J6.31 (VIN)
unnamed: J5.32, J6.32 (GND)
unnamed: R3.2, U3.47 (USB_DP)
unnamed: R4.2, U3.46 (USB_DM)
VBUS: C1.1, J1.A4 (VBUS), J1.A9 (VBUS), J1.B4 (VBUS), J1.B9 (VBUS), U1.3 (VI)
nCS: J2.5, J3.5 (~CS), J4.5 (~CS), U4.10 (A8)
nCS_3V3: U3.7 (GPIO5), U4.14 (B8)
nRD: J2.4, J3.4 (~RD), J4.4 (~RD), U4.9 (A7)
nRD_3V3: U3.6 (GPIO4), U4.15 (B7)
nWR: J2.3, J3.3 (~WR), J4.3 (~WR), U4.8 (A6)
nWR_3V3: U3.5 (GPIO3), U4.16 (B6)

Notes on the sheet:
Status LEDs and mode button
Make sure R3 and R4 are close to RP2040
Note that ERC check might complain that these bidirectional ports are connected to GND. This should be fine as DIR is directly connected to VCCA, so whenever port A is powered these ports are inputs. If DIR is low, there is no power to cause any harm on port A.
Flash Memory
These are transceivers but used in only one direction. These have been tested in a different project with bi-directional communication and they were cheaply available.
Power and USB
Make sure C10 is close to pin 44 of RP2040
Crystal
Make sure C8 is close to pin 45 of RP2040
5V to 3.3V
Cartridge Connectors
Game Boy Power detection

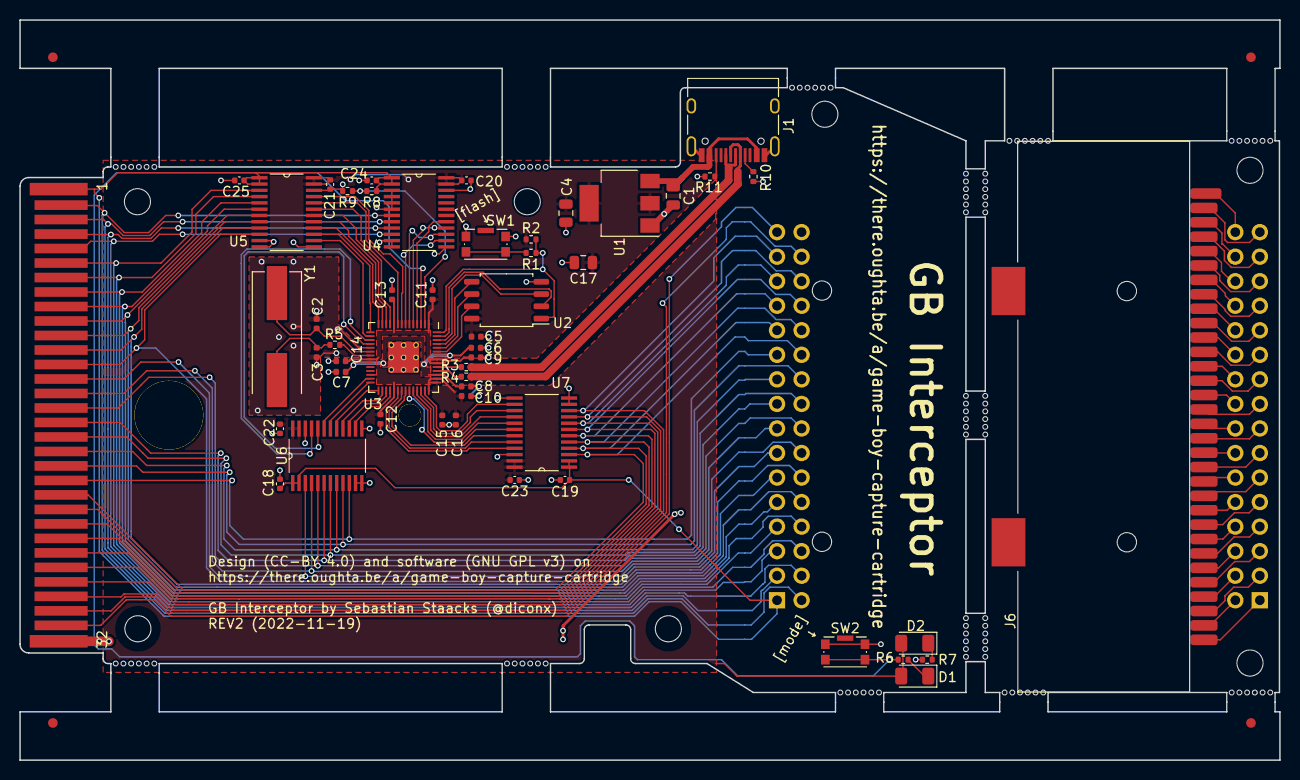
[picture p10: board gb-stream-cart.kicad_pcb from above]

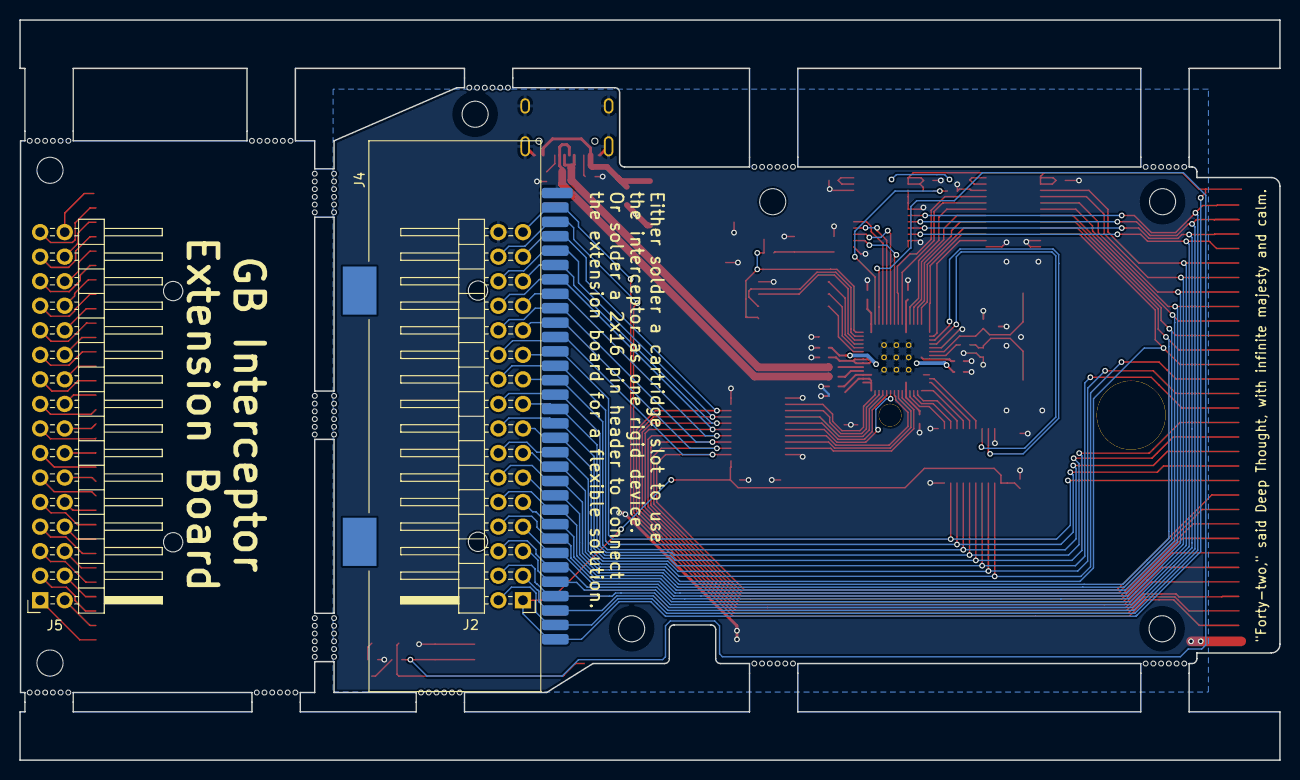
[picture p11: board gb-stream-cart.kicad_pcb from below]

Board: 2 copper layers, 130.4 x 76.6 mm, 76 parts (3 on the bottom side), 115 nets.

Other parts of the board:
mouse-bite-3mm-slot, mouse-bite-3mm-slot#2, mouse-bite-3mm-slot#10: VAL**; mouse-bite-3mm-slot
mouse-bite-3mm-slot#3, mouse-bite-3mm-slot#4, mouse-bite-3mm-slot#5, mouse-bite-3mm-slot#6, mouse-bite-3mm-slot#7, mouse-bite-3mm-slot#8, mouse-bite-3mm-slot#9, mouse-bite-3mm-slot#11, mouse-bite-3mm-slot#12, mouse-bite-3mm-slot#13: VAL**; half-mouse-bite-3mm-slot

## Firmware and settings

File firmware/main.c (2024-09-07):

#include "main.h"

#include <stdio.h>
#include "pico/stdlib.h"
#include "pico/multicore.h"
#include "pico/mutex.h"

#include "bsp/rp2040/board.h"
#include "bsp/board_api.h"
#include "tusb.h"
#include "usb_descriptors.h"
#include "hardware/clocks.h"
#include "hardware/dma.h"

#include "cpubus.h"
#include "ppu.h"
#include "osd.h"
#include "debug.h"
#include "gamedb/game_detection.h"

#include "jpeg/base_jpeg.h"
#include "jpeg/base_jpeg_no_chroma.h"

#include "screens/default.h"
#include "screens/off.h"
#include "screens/error.h"

bool frameSending = false;

bool modeButtonDebounce = true;

uint fallbackFrameIndex = 0;
enum FallbackScreenType {FST_NONE = 0, FST_DEFAULT, FST_OFF, FST_ERROR} fallbackScreenType = FST_NONE;  

int dmaChannel;
dma_channel_config dmaConfig;

bool dmgColorMode = false;

bool includeChroma = true;
bool is30fpsFrame = true;

void setupGPIO() {
    gpio_init(GBSENSE_PIN);
    gpio_init(LED_SWITCH_PIN);
    gpio_set_dir(GBSENSE_PIN, GPIO_IN);
    
    //IMPORTANT: Since the mode button directly connects this GPIO pin to ground, we only want to drive it to the ground state to enable the LED. Disabling the LED is done by disabling the output, never by driving actively to HIGH as this might cause a short circuit if the button is pressed at the same time.
    gpio_put(LED_SWITCH_PIN, 0);
    gpio_set_dir(LED_SWITCH_PIN, GPIO_IN);
    gpio_pull_up(LED_SWITCH_PIN);
}

void ledOn() {
    gpio_set_dir(LED_SWITCH_PIN, GPIO_OUT);
}

void ledOff() {
    gpio_set_dir(LED_SWITCH_PIN, GPIO_IN);
}

void checkModeSwitch() {
    #ifndef BASE_VIDEO_MODE
    if (gpio_get(LED_SWITCH_PIN)) {
        if (!modeButtonDebounce) {
            modeButtonDebounce = true;
            //Button pressed, switch mode
            frameBlending = !frameBlending;
            if (frameBlending) {
                dmgColorMode = !dmgColorMode;
                frontBuffer[JPEG_CHROMA_OFFSET] = dmgColorMode ? 0b10001000 : 0x00;
                readyBuffer[JPEG_CHROMA_OFFSET] = dmgColorMode ? 0b10001000 : 0x00;
            }
            renderOSD(frameBlending ? "Blending ON" : "Blending OFF", 0x03, 0x00, MODE_INFO_DURATION);
        }
    } else if (modeButtonDebounce) {
        modeButtonDebounce = false;
    }
    #endif
}

bool static inline isGameBoyOn() {
    return gpio_get(GBSENSE_PIN);
}

void setupDMA() {
    dmaChannel = dma_claim_unused_channel(true);
    dmaConfig = dma_channel_get_default_config(dmaChannel);
    channel_config_set_read_increment(&dmaConfig, true);
    channel_config_set_write_increment(&dmaConfig, true);
}

void loadFallbackScreen(uint8_t * screen, enum FallbackScreenType type) {
    osdPosition = SCREEN_H;
    dma_channel_configure(dmaChannel, &dmaConfig, backBuffer, screen, SCREEN_SIZE / 4, true);
    while (dma_channel_is_busy(dmaChannel)) {
        tud_task();
    }
    fallbackScreenType = type;
    renderText(VERSION, 0x00, 0x03, (uint8_t *)backBuffer, SCREEN_W-(sizeof(VERSION)-1)*8, 1);
}

bool usbSendFrame() {
    if (tud_video_n_streaming(0, 0)) {
        if (!frameSending) {
            if (swapFrontbuffer()) {
                is30fpsFrame = !is30fpsFrame; //If clock is determined by the Game Boy and if we include Chroma, we only send every second frame (i.e. 30fps)
                if (is30fpsFrame || !includeChroma || !running) {
                    frameSending = true;
                    tud_video_n_frame_xfer(0, 0, (void*)(frontBuffer + (includeChroma || !running ? 0 : JPEG_HEADER_SIZE - JPEG_HEADER_SIZE_NO_CHROMA)), includeChroma || !running ? FRAME_SIZE : FRAME_SIZE_NO_CHROMA);
                }
                return true;
            }
        }
    } else {
        frameSending = false;
    }
    return false;
}

void updateFallbackScreen() { 
    fallbackFrameIndex++;
    if (fallbackFrameIndex >= 160)
        fallbackFrameIndex = 0;
    for (int x = 0; x < SCREEN_W/2; x++) {
        if (x < fallbackFrameIndex && x + 80 > fallbackFrameIndex) {
            backBuffer[63*SCREEN_W + 80 + x] = 0x03;
            backBuffer[63*SCREEN_W + 79 - x] = 0x03;
        } else {
            backBuffer[63*SCREEN_W + 80 + x] = 0x00;
            backBuffer[63*SCREEN_W + 79 - x] = 0x00;
        }
    }
}

void fillBufferWithBaseJpeg(uint8_t * target, bool includeChroma) {
    int chromaOffset = (includeChroma ? 0 : JPEG_HEADER_SIZE - JPEG_HEADER_SIZE_NO_CHROMA);
    int headerSize = (includeChroma ? JPEG_HEADER_SIZE : JPEG_HEADER_SIZE_NO_CHROMA);
    for (int i = 0; i < headerSize; i++)
        target[i + chromaOffset] = (includeChroma ? base_jpeg : base_jpeg_no_chroma)[i];
    int fullSize = (includeChroma ? FRAME_SIZE : FRAME_SIZE_NO_CHROMA);
    for (int i = JPEG_DATA_SIZE + headerSize; i < fullSize; i++)
        target[i + chromaOffset] = (includeChroma ? base_jpeg : base_jpeg_no_chroma)[i];
}

void updateIncludeChroma() {
    fillBufferWithBaseJpeg((uint8_t *)frontBuffer, includeChroma || !running);
    fillBufferWithBaseJpeg((uint8_t *)readyBuffer, includeChroma || !running);
    fallbackScreenType = FST_NONE;
}

int main(void) {
    set_sys_clock_khz(250000, true);

    board_init();
    setupDMA();
    setUniqueSerial();
    tud_init(BOARD_TUD_RHPORT);
    stdio_init_all();
    setupGPIO();
    prepareJpegEncoding();

    multicore_launch_core1(handleMemoryBus);
    
    while (1) {

        printf("Waiting for game.\n");
        updateIncludeChroma();
        uint lastFrame = timer_hw->timerawl;
        while (!running) {
            if (isGameBoyOn()) {
                if (fallbackScreenType == FST_NONE || fallbackScreenType == FST_OFF) {
                    loadFallbackScreen(default_raw, FST_DEFAULT);
                    renderText("Waiting for game...", 0x03, 0x00, (uint8_t *)backBuffer, 5, 79);
                    if (!includeChroma)
                        renderText("   60 fps mode.\nSwitch to 30fps if\nthere are problems.", 0x03, 0x00, (uint8_t *)backBuffer, 5, 100);
                    readyBufferIsNew = false;
                    startBackbufferToJPEG(false);
                }
            } else {
                if (fallbackScreenType == FST_NONE || fallbackScreenType == FST_DEFAULT || fallbackScreenType == FST_ERROR) {
                    loadFallbackScreen(off_raw, FST_OFF);
                    renderText("The Game Boy\nis turned off", 0x03, 0x00, (uint8_t *)backBuffer, 40, 79);
                    if (!includeChroma)
                        renderText("   60 fps mode.\nSwitch to 30fps if\nthere are problems.", 0x03, 0x00, (uint8_t *)backBuffer, 5, 100);
                    readyBufferIsNew = false;
                    startBackbufferToJPEG(false);
                }
            }
            if (readyBufferIsNew && (!includeChroma || ((uint)(timer_hw->timerawl - lastFrame) > 33333))) {
                if (usbSendFrame()) {
                    lastFrame = timer_hw->timerawl;
                    updateFallbackScreen();
                    startBackbufferToJPEG(false);
                }
            } else
                continueBackbufferToJPEG();
            tud_task();
        }

        ledOn();
        printf("Game started. Cycle ratio: %d\n", cycleRatio);
        updateIncludeChroma();
        ppuInit();

        uint lastCycle = cycleIndex;
        uint8_t vblank = false;
        #ifdef DEBUG_PPU_TIMING
            uint lastPPUTimingRequest = timer_hw->timerawl;
        #endif
        while (running) {
            #if defined(DEBUG_MEMORY_DUMP)
                // Only debug opcodes or memory via serial without trying to render at the same time
                sleep_ms(1000);
                tud_task();
                #ifdef DEBUG_MEMORY_DUMP
                    dumpMemory();
                #endif
            #else
                uint steps = (uint)(cycleIndex - lastCycle);
                lastCycle += steps;
                DEBUG_MARK_VBLANK_ADJUST
                int adjust = vblankOffset; //We work with a copy as another thread may change this at any time
                if (adjust >= 0) {
                    if (adjust > 10) //Limit the amount of catching up per step to avoid to unpleasant results
                        adjust = 10;
                    vblankOffset -= adjust; //Yes, there might be a race condition here, but if another thread has calculated a new value for vblank in the meantime, it used the old state of the PPU, so it still should be adjusted and if it wrote this value between reading and decrementing, then we still only make a mistake of a few cycles which we will eventually fix anyway
                    ppuStep(steps + adjust);
                } else {
                    //else do not perform step to wait for the real Game Boy
                    vblankOffset += steps;
                }

                #ifdef DEBUG_PPU_TIMING
                    if ((uint)(timer_hw->timerawl - lastPPUTimingRequest) > 2e6) { //Wait a moment to avoid influencing the measurement by the serial output
                        lastPPUTimingRequest = timer_hw->timerawl;
                        recordPPUTiming = true;
                    }
                    if (ppuTimingReady) {
                        printPPUTiming();
                    }
                #endif

                if (!vblank && y >= SCREEN_H) {
                    vblank = true;
                    ledOff(); //Switches the LED GPIO to input to allow to use the same GPIO pin to read the mode button state, however, in order to allow the line to settle first, we do the read-out at the end of vblank and then re-enable the LED
                    if (!gameDetected) {
                        if (detectGame()) {
                            renderOSD(gameInfo.title, 0x00, 0x03, GAME_DETECTED_INFO_DURATION);
                        }
                    }
                } else if (vblank) {
                    if (y < SCREEN_H) {
                        vblank = false;
                        checkModeSwitch();
                        ledOn();
                    }
                }

                tud_task();
                if (renderState == done) {
                    usbSendFrame();
                }
            #endif
        }

        ledOff();
        if (error != NULL) {
            mutex_enter_blocking(&cpubusMutex); //Grab mutex immediately.
            loadFallbackScreen(error_raw, FST_ERROR);
            renderText("Sorry,\nsomething\nwent wrong...", 0x03, 0x00, (uint8_t *)backBuffer, 44, 72);
            renderText((const char *)error, 0x02, 0x00, (uint8_t *)backBuffer, 4, 110);
            readyBufferIsNew = false;
            startBackbufferToJPEG(false);
            dumpMemory();
            dumpBus();
            stdio_flush();
            mutex_exit(&cpubusMutex);
        }
    }

    return 0;
}

// Invoked when device is mounted
void tud_mount_cb(void) {
}

// Invoked when device is unmounted
void tud_umount_cb(void) {
}

// Invoked when usb bus is suspended
// remote_wakeup_en : if host allow us  to perform remote wakeup
// Within 7ms, device must draw an average of current less than 2.5 mA from bus
void tud_suspend_cb(bool remote_wakeup_en) {
    (void) remote_wakeup_en;
}

// Invoked when usb bus is resumed
void tud_resume_cb(void) {
}

void tud_video_frame_xfer_complete_cb(uint_fast8_t ctl_idx, uint_fast8_t stm_idx) {
    (void)ctl_idx; (void)stm_idx;
    frameSending = false;
}

int tud_video_commit_cb(uint_fast8_t ctl_idx, uint_fast8_t stm_idx, video_probe_and_commit_control_t const *parameters) {
    (void)ctl_idx; (void)stm_idx;
    #ifdef BASE_VIDEO_MODE
    includeChroma = true;
    #else
    includeChroma = parameters->dwFrameInterval > 200000 /*slower than 50fps*/;
    #endif
    updateIncludeChroma();
    return VIDEO_ERROR_NONE;
}

void tud_cdc_line_state_cb(uint8_t itf, bool dtr, bool rts)  {
	(void)itf;
	(void)rts;

	if (dtr) {
        fflush(stdout);
		printf("\n\nGB Interceptor\nVersion ");
        printf(VERSION);
        printf("\n\n");
	}
}

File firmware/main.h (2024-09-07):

#ifndef GBINTERCEPTOR_MAIN
#define GBINTERCEPTOR_MAIN

#define GBSENSE_PIN 0

#define LED_SWITCH_PIN 1
#define LED_PIN_MASK 0x02

#define BASEVERSION "1.2.0"

#ifdef BASE_VIDEO_MODE
#define VERSION BASEVERSION "B"
#else
#define VERSION BASEVERSION
#endif

//On-screen display
#define MODE_INFO_DURATION 100 //Duration of the mode info in frames
#define GAME_DETECTED_INFO_DURATION 200 //Duration of the mode info in frames

#endif

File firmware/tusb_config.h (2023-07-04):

/*
 * The MIT License (MIT)
 *
 * Copyright (c) 2019 Ha Thach (tinyusb.org)
 *
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
 */

#ifndef _TUSB_CONFIG_H_
#define _TUSB_CONFIG_H_

#ifdef __cplusplus
 extern "C" {
#endif

//--------------------------------------------------------------------+
// Board Specific Configuration
//--------------------------------------------------------------------+

// RHPort number used for device can be defined by board.mk, default to port 0
#ifndef BOARD_TUD_RHPORT
#define BOARD_TUD_RHPORT      0
#endif

// RHPort max operational speed can defined by board.mk
#ifndef BOARD_TUD_MAX_SPEED
#define BOARD_TUD_MAX_SPEED   OPT_MODE_DEFAULT_SPEED
#endif

//--------------------------------------------------------------------
// Common Configuration
//--------------------------------------------------------------------

// defined by compiler flags for flexibility
#ifndef CFG_TUSB_MCU
#error CFG_TUSB_MCU must be defined
#endif

#ifndef CFG_TUSB_OS
#define CFG_TUSB_OS           OPT_OS_NONE
#endif

#ifndef CFG_TUSB_DEBUG
#define CFG_TUSB_DEBUG        0
#endif

// Enable Device stack
#define CFG_TUD_ENABLED       1

// Default is max speed that hardware controller could support with on-chip PHY
#define CFG_TUD_MAX_SPEED     BOARD_TUD_MAX_SPEED

/* USB DMA on some MCUs can only access a specific SRAM region with restriction on alignment.
 * Tinyusb use follows macros to declare transferring memory so that they can be put
 * into those specific section.
 * e.g
 * - CFG_TUSB_MEM SECTION : __attribute__ (( section(".usb_ram") ))
 * - CFG_TUSB_MEM_ALIGN   : __attribute__ ((aligned(4)))
 */
#ifndef CFG_TUSB_MEM_SECTION
#define CFG_TUSB_MEM_SECTION
#endif

#ifndef CFG_TUSB_MEM_ALIGN
#define CFG_TUSB_MEM_ALIGN        __attribute__ ((aligned(4)))
#endif

//--------------------------------------------------------------------
// DEVICE CONFIGURATION
//--------------------------------------------------------------------

#ifndef CFG_TUD_ENDPOINT0_SIZE
#define CFG_TUD_ENDPOINT0_SIZE    64
#endif

//------------- CLASS -------------//
// The number of video control interfaces
#define CFG_TUD_VIDEO            1
#define CFG_TUD_CDC              0
#define CFG_TUD_MSC              0
#define CFG_TUD_HID              0
#define CFG_TUD_MIDI             0
#define CFG_TUD_VENDOR           0

// The number of video streaming interfaces
#define CFG_TUD_VIDEO_STREAMING  1

//Bulk transfer mode (in contrast to isochronous mode)
#define CFG_TUD_VIDEO_STREAMING_BULK 1

// video streaming endpoint size
#if CFG_TUD_VIDEO_STREAMING_BULK == 1
    #define CFG_TUD_VIDEO_STREAMING_EP_BUFSIZE  2048
#else
    #define CFG_TUD_VIDEO_STREAMING_EP_BUFSIZE  1023
#endif

#define CFG_TUD_CDC_RX_BUFSIZE   (TUD_OPT_HIGH_SPEED ? 512 : 64)
#define CFG_TUD_CDC_TX_BUFSIZE   (TUD_OPT_HIGH_SPEED ? 512 : 64)

// CDC Endpoint transfer buffer size, more is faster
#define CFG_TUD_CDC_EP_BUFSIZE   (TUD_OPT_HIGH_SPEED ? 512 : 64)

#ifdef __cplusplus
 }
#endif

#endif /* _TUSB_CONFIG_H_ */

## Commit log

2022-12-16 Initial commit of locally developed project to prepare release.
    [case.blend, case_bottom.stl, case_button.stl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]
2022-12-27 Improve USB descriptors: Device name and calculation of bitrate limits.
2022-12-27 Add case variant by AngryHelder.
    [GB Interceptor Bottom Base.step, GB Interceptor Bottom Cap.step, GB Interceptor Bottom.step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]
2022-12-29 Allow setting arbitrary framerates below 29fps, some cleanup and greeting line on terminal.
2022-12-29 Fix flickering on MacOS (Really stupid error forcing new USB frames to be sent during rendering of a line instead of hblank and vblank)
    [main.c]
2022-12-29 Allow restart without waiting for the Game Boy to be turned off. This should fix #4, but has not yet been tested.
    [main.c]
2022-12-30 Added support for DMA from cartridge. (Not really tested. I thought I found this happening in Donkey Kong III and implemented it. What I did not notice was that the real Game Boy also crashed and tha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
2022-12-30 Fixes for original Game Boy (DMG): Detect return after DMA from SP access to fix Donkey Kong Land. Ignore address on bus when reading from VRAM and use emulated address instead to fix several graphic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
    [main.c]
2023-01-10 Limit allowed allowed framerate steps to fix issues with apps that freeze otherwise (probably trying to enumerate all options?)
    [main.h]
2023-01-11 Add on screen display to indicate if frame blending is on or off and default to off on start.
2023-01-14 Fix Interceptor not working after power cycle on some outlier PCBs. Manufacturing tolerances can lead to edge cases in which the olscillator takes to long to settle, which leads to the Interceptor wo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
    [main.h]
2023-01-14 Increase lead in time for gathering clock statistics, fixing incorrect clocks an error in many games on the Game Boy Pocket.
    [main.h]
2023-01-20 Add game detection. (Note that most hashes have been generated automatically, but game detection only really becomes relevant for game-specific fixes and time trials, at which point the relevant hash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
    [games.csv]
2023-01-22 Game-specific fixes for DMA returns and fixin Alien vs. Predator
    [games.csv]
2023-01-26 Game-specific fixes by reconstructing memory addresses based on conditional jumps and fixing Bonk's Adventure
    [games.csv]
2023-01-27 Option to allow some games to sync to vblank interrupt even if it has been delayed and use that to fix TMNT.
    [games.csv]
2023-01-28 Replace reconstuct fix function by a non-automated but more efficient and more flexible system of mapping fix operations to the outcome of specific branched. Also introducting a simple fix definition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
    [games.csv]
2023-01-28 Fix rolling horizontal line in Kirby's Dream Land 2.
    [games.csv]
2023-01-29 Game-specific setting to copy some HRAM/IO addresses during DMA and use it to fix Tetris 2
    [games.csv]
2023-01-30 Fix vblankOffset output in PPU debugging.
    [debug.h]
2023-01-30 Allow disabling of tight loop sync events. And fix Samurai Shodown with branch based sync.
    [games.csv]
2023-01-30 Fix rendering of window if it is enabled mid-frame. (Fixes text banners in Samurai Shodown)
2023-01-31 Fix player sprite in Fighting Simulator.
    [games.csv]
2023-02-03 Improve (but not entirely fix) story text of Batman the animated series.
    [games.csv]
2023-02-04 Fix menu of Mole Mania
    [games.csv]
2023-02-04 Remove PC jump requirement from interrupt detection to fix Tiny Toons Bab's Big Break. This is a tricky one as this requirement is supposed to prevent an edge case in which a game has a 1 cycle opcod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
2023-02-04 Wait longer for return instruction after DMA before giving up. Fixes Dr. Franken which counts down 0x40*4=256 cycles instead of 40*4=160.
2023-02-04 Add a lower frame blending mode and use this as default. Also change order of modes when pressing the mode button.
2023-02-10 Further improve window logic: Only pause internal line counter if the window has been disabled midframe. This fixes the credit banners in Prehistoric Man and possibly other games that were broken by 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
    [games.csv]
2023-02-10 Increase chunks at which frame blending is calculated. This slightly reduces the load on the PPU core at the cost of slightly less responsive USB communication tasks. Seems to be a better compromise 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
2023-02-10 Interrupt sync for stat interrupt with LY=LYC condition. (Fixes rolling line in Prehistorik Man)
2023-02-11 Increase halt timeout for edge cases of halting for an entire frame with slight clock differences (Fixes occasional crash at level start of Prehistorik Man)
2023-06-10 USB Video in bulk transfer mode. This code is currently deactivated as it seems that there is no advantage for this variant. I would guess that the overhead of many 64B transfers on the rp2040 using 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
    [tusb_config.h]
2023-07-01 MJPEG encoding! Thanks to Ikadzuchi's suggestion (see #17) this enables 60fps and fixes Apple compatibility (issue #1). This commit has a wide impact on several aspects: Idle screens are now 2bit gra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
    [jpeg.c]
2023-07-02 Fix USB enumeration problems (descriptor mix-up of bulk and isochronous settings, also moved intiial loading of base jpeg to main to do it only once while still handling USB communications in paralle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
    [jpeg.c, main.c, tusb_config.h]
2023-07-02 Switch to bulk transfer mode. (Turns out that the mix-up in the defines (see previous commit) means that I have been testing in bulk mode all along and that isochronous mode caused most of the troubl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
    [jpeg.c, tusb_config.h]
2023-07-04 Fix missing EOI because of 32bit copy.
    [main.c]
2023-07-04 Add chroma channels to MJPEG to conform to UVC 1.5 and fix compatibility with OBS
    [main.h]
2023-07-04 Fix missing EOI again and USB optimizations (in particular disabling CDC as it usually is not required by the user).
    [tusb_config.h]
2023-07-06 Fix LYC=LY STAT interrupt detection causing massive negative cycle offset if triggered on LYC=0 with LY on line 153.
2023-07-06 Do not sync on interrupts that occur shortly after writing to the STAT register to avoid the STAT interrupt bug that occurs on DMG and GBP.
2023-07-08 Limit fps choices to 30fps and 60fps. If 60fps is selected, no chroma channel is used in-game. If 30fps is selected, the higher compatibility with chroma is used and only every second frame is transf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
2023-08-05 Limit framerate of standby screen to 30fps if in 30fps mode and make this release 1.2.0.
2024-01-14 Update main.yml: install arm-none-eabi-gcc toolchain
2024-01-14 Update main.yml: pin pico-sdk to a specific commit
2024-01-14 Update main.yml: pin version of pico-sdk... not gbinterceptor
2024-01-15 Update main.yml: pico-sdk 1.5.1, tinyusb 0.16.0
2024-01-15 Update main.c: tinyusb bsp/board-related include files
2024-09-07 Update Pico SDK to 2.0.0 for automatic builds. Local testing seems to not require any changes, so let's see if automatic builds are still working properly after such a long time...
2024-09-07 Allow building a base video mode version by setting the precompiler define BASE_VIDEO_MODE. This mode only accepts 30fps and does not allow enabling frame blending or green mode. This is not relevant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

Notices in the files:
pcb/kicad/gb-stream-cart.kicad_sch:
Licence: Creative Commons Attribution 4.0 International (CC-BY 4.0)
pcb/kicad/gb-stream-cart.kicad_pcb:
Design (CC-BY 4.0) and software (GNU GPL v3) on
